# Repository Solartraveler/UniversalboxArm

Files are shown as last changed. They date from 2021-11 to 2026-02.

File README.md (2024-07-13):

# UniversalboxArm

## Idea

Have a box for experiments and easy testing with a CPU which is more powerful than an AVR (Arduino)
and uses less energy than a Raspberry Pi.
Then add some common peripherals and fit this into a case.

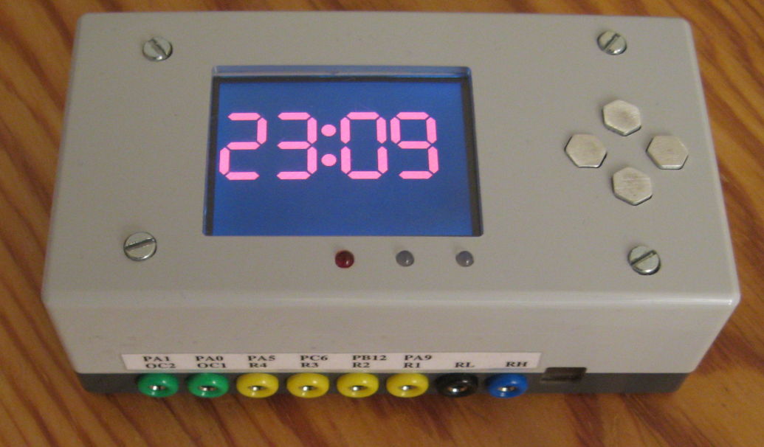
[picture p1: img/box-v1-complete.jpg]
PCB version 1 running, showing a clock


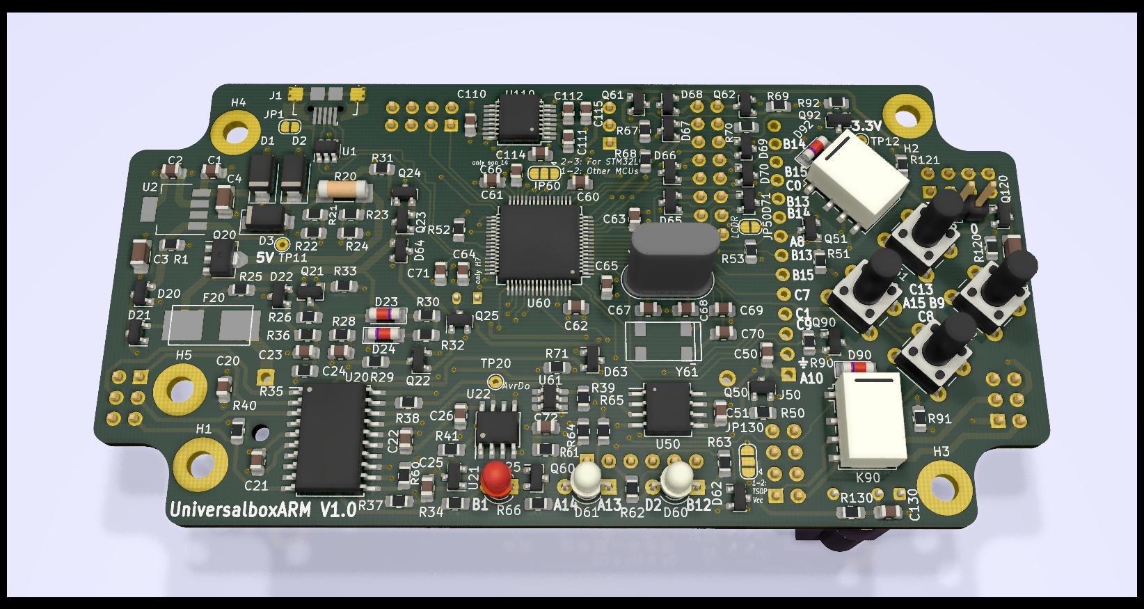
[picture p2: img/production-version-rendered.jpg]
Kicad rendering




## Features

The following hardware has been added. Not everything is required to be populated on the PCB.

- Various 64Pin STM32 MCUs possible

    - STM32L452RET (80MHz, 160KiB RAM) tested

- Runs from USB power

- Can run from a LiFePO battery and charge it

- 2x red-green duo LEDs

- Four buttons

- LCD socket

    - 128x128 (ST7735, tested), 160x128 (ST7735, untested) or 320x240 (ILI9341, tested) RGB LCDs are possible

- Four Relays

- External flash with up to 8MiB

- RS232 level converter

- IR receiver

- WLAN with an ESP-01

- Two open collector outputs

- Several ESD protected in and outputs

- AVR coprocessor for resetting and charge control

## Status

### Software

#### DFU loader for the ARM

A loader for the STM32 MCU is feature complete.

- Can be used by the common dfu-util delivered by the usual Linux distributions (like Debian)

- Accepts applications within a common .tar file together with some metadata

    - With the STM32L452 having 160KiB RAM, the tar file may be up to 128KiB in size.
Needing 2.5KiB overhead for the .tar format and the metadata, the binary may be up to 125.5KiB in size and after starting can use the full 160KiB for code + data.
Executing from RAM results in about 80% of the speed compared with executing from flash with the same CPU frequency.

- The application can be run directly from the RAM or stored into the external flash

    - Transferring to RAM is much faster than writing to the flash. Also there is no worry about the internal flash lifetime.

- Formats the external flash as FAT filesystem

- Allows configuring one of the three LCD sizes

    - Configuration is stored on the external flash and can be read by other applications

- With the four keys and the LCD, applications can be selected from the external flash and run without an USB connection

    - Can set one application as autostarting on power-on

- Each application can have a short descriptive text and explanation image to be shown on the LCD

    - The text can be up to 1KiB long and is taken from the readme.md of each firmware

    - The image is 3 bit RGB and must have the size of the selected LCD or one of the possible smaller LCDs.
Moreover the compressed data needs to fit within 7000byte. Due to RAM constraints, each 4x4 pixel block can not display pixel with more than two different colors.

#### Firmware for the coprocessor

- A long press of the left key resets the ARM processor

- A long press of the right key toggles if a reset should start the DFU bootloader from ST or the application from the flash (most likely the DFU bootloader described above)

- Supports a SPI communication to the ARM processor

    - ARM processor can request a reset

    - ARM processor can enable a watchdog

- The battery can be charged

- A wakeup time for the ARM processor can be set

#### More software

Software testing all the hardware to be working as intended has been written for the ARM processor and the AVR coprocessor.

There is a implementation for using the 8MiB flash as USB pen drive.

One application implements an NTP client and uses the display as digital clock.

See [readme.md](src/apps/readme.md)

### Hardware

The PCB version 1 is working, but a lot of patching is required at several peripherals to use them.
With 380µA, the power down consumption is too high, as this would discharge a full battery within 65 days, and then the LiFePo must be considered defective.
The required changes are documented. Recreating a PCB version 1 is discouraged.
Instead the required changes need to be integrated into a version 2.

Milling the case is done.
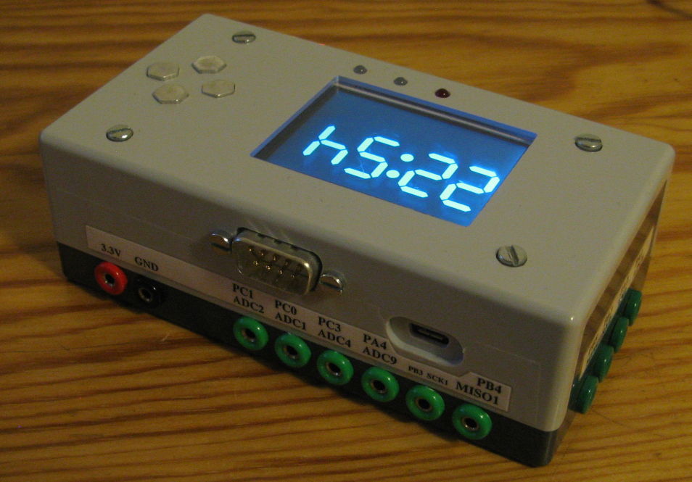
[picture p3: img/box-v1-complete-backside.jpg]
PCB version 1 running, backside


See [readme.md](case/readme.md)

## Using a breadboard

Without soldering an own PCB, some of the apps can be used together with a Nucleo evaluation board from ST.
Then it is just a connection of some wires.
Instead of the onboard flash, the SD card can be used to store settings.
Many of the breakout boards for the LCDs already have a SD card slot on the backside.
The serial port is provided by the nucleo board over USB itself.
One LED and one button is provided by the nucleo board, thee additional buttons can be connected, everthing else is currently missing support.
Currently only the blinky-hal, test-everything and adc-scope apps have been tested on a nucleo with a STM32F411.
As the used board with a STM32F411 only has 128KiB of RAM, it will never be possible to load and execute all apps from RAM there.
However all could made working when running from flash.

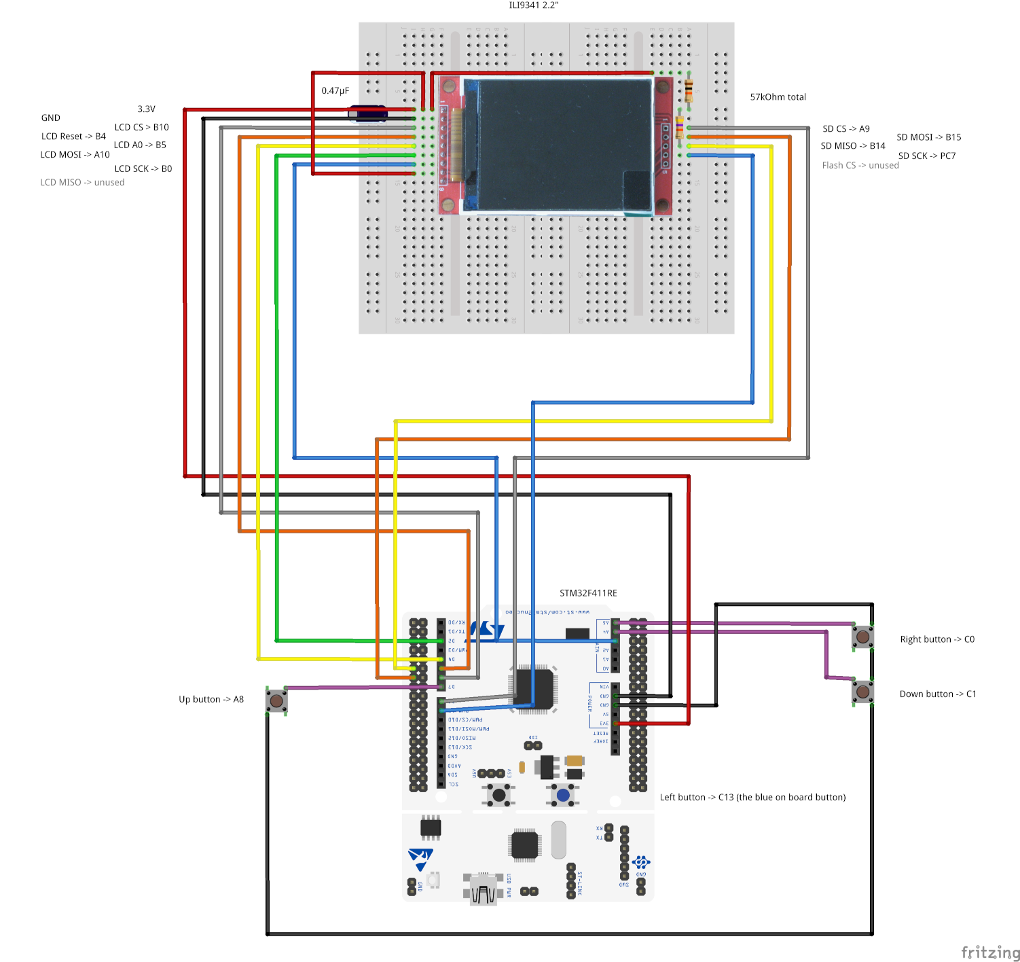
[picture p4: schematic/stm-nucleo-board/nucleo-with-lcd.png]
Wiring of a nucleo to the LCD and SD card


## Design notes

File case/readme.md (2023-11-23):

# Case

The openings are milled with a 2mm flute into a [BOPLA E430](https://www.bopla.de/en/enclosure-technology/element-universal/enclosure-6) case.

Everything is really cramped together in there and still could be placed some 0.1mm to look better. But it works.

Graphic of heights in the case

A E435 with a height of 65mm instead of the 40mm would relax the spacing a lot.

The mill in use has a backslash of 0.1mm, so the files might be modified if the mill is better/worse than this.

The -test files are there to mill a sheet of cheap plastic to test out all the dimensions and to have something to position the mill right on the real case.

The left side could not be milled due to the limit in Z direction. There are no connections on the right and bottom.

# Buttons
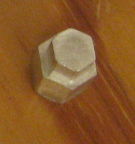
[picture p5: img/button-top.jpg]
Aluminum button top

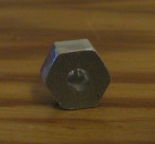
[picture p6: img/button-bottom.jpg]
Aluminum button bottom


The buttons are milled from 10mm aluminum plates (actually a 10.1mm was delivered).
It is difficult to get them right, as 0.2mm wrong in the one or other direction let them wiggle or let them sit so tight they are pressed permanently.

Also when buying 10mm alumium plates, they might be up to +-0.5mm in thickness and the files for milling need some adjustents according to the exact value.

Note, by screwing the case together, the surface also bends a little bit inward, which has to be taken care of too.

## File formats

.FCStd -> .step -> .heeks -> .ngc

## FreeCAD
All models were first created with [FreeCAD](https://www.freecad.org/) 0.21. If in doubt, try only this version to open the files.

FreeCAD saves its files as .FCstd. The 3D model is exported from FreeCAD as .step file.

## HeeksCAD
[HeeksCAD](https://github.com/Heeks/heekscad) together with [HeeksCNC](https://github.com/Heeks/heekscnc) Is used to create the paths for the CNC mill.

HeeksCAD imports .step files, saves them to .heeks and creates .ngc files.

Don't try to get HeeksCNC to work on a modern (Debian 12 as of writing this) system (HeeksCAD does work), it needs Python 2 with boost compiled against Python 2.
So instead set up a VM with Debian 10. HeeksCNC works fine with X-forwarding.

FreeCAD could be used to create the milling paths too, but the ones from HeeksCNC are better (as of 2023).

## Candle2

[Candle2](https://github.com/Schildkroet/Candle2) now reads the .ngc files and drives a modified Proxxon MF70 mill with [grbl](https://github.com/grbl/grbl).

## xfig

The .fig files can be opened by [xfig](https://mcj.sourceforge.net/). From there the .svg or .pdf files are exported.

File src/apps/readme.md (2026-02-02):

# Firmwares for the STM32L452 processor

## Common

Library code used by multiple projects.

## 01-blinky-hal

Project showing that running the ARM works. The LEDs D61 and D62 are blinking and
are responding to the four input keys. This project uses the HAL library from ST.

## 02-test-everything-hal

Uses a RS232 port with 19200baud to allow controlling all connected hardware.

## 03-loader

__Main firmware__ intended to be progammed into the internal flash.
Provides a DFU device via USB to upload new programs.
Also writes a configuration in the external flash for the selected LCD type.
Can store and load programs from the external flash. Formatting can be done too.
Debug prints are available over the RS232 port with 19200baud.

## 04-coprocessor-uart-forward

If the coprocessor is running the 02-test-everything firmware, it prints data at 1200baud on the pins connected to the ARM.
With this firmware the data is forwared to the RS232 port with 19200baud and prints the data on the LCD too.

## 05-coprocessor-control

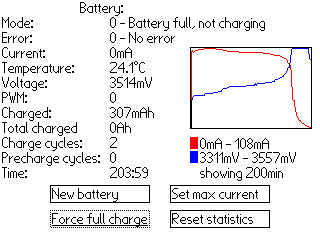
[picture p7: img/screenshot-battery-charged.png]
Screenshot after charging the battery


If the coprocessor is running the 05-charger-with-spi firmware, this firmware allows reading out the charger state, resetting
the charger state and playing with the power off features.
Debug prints are available over the RS232 port with 19200baud.

## 06-usb-mass-storage

Connect the external SPI flash as USB mass storage device to the PC, allows reading and writing files on the disk.
As always, Debug prints are available over the RS232 port with 19200baud.

## 07-ntp-clock

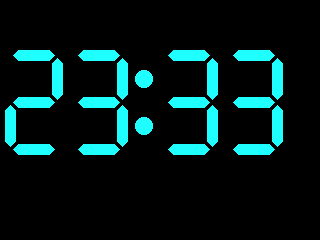
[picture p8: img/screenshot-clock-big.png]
Screenshot of the big clock


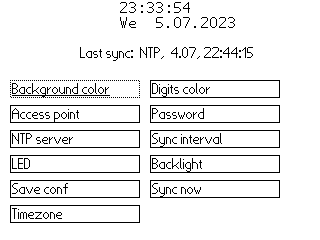
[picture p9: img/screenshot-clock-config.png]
Screenshot of the configuration


Shows a big digital clock on the screen. Foreground and background color can be configured out of 256 colors.
The clock is synced over WIFI with an NTP server, therefore AP, password and NTP server can be set.
The backlight level and timezone can be set and the internal clock is calibrated automatically
when there are two syncs with enough time inbetween.
If a battery is connected, the clock continues to run while the device is off.
To allow updateing the GUI while the WIFI is served, FreeRTOS is used.
All settings are saved to the filesystem.
Debug prints are available over the RS232 port with 19200baud.
Also entering the AP and password is much easier over the RS232 port.

## 08-freertos-helloworld
Simple example how to use FreeRTOS.
Starts four threads, one for reading the serial port, one for resetting the watchdog, one for flashing the LEDs and one for reading the buttons.

## 09-gamebox

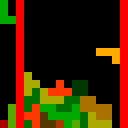
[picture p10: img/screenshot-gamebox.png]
Screenshot of the gamebox, playing tetris


Port of an old project, originally written for an AVR with a red/green LED matrix.
Play Tetris, Snake, Four winns, Reversi, Race or Pong with just 16x16 pixels and 4 bit colors.
Also contains a demo.
Best used with an analogue joystick. But the input keys work too.
Tetris, Snake, Four winns, Reversi can also be played over the RS232 input, using w-a-s-d as cursor and space for enter.
The sourcecode is pretty old and still commented in german.
Running the gamebox on the AVR can be watched on [Youtube](https://www.youtube.com/watch?v=83r08iD9ZAA)
The connection of the analogue joystick to the STM32 is as follow:
Schematic for d-sub connection

## 10-infrared-decoder

Prints the protocol, address, command and flags of many infrared remote controls on the LCD and
serial port.

## 11-adc-scope

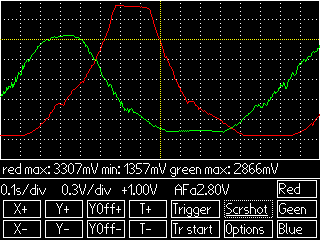
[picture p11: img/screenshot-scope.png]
Screenshot of the scope


Shows the analogue inputs on the display. Only supports 320x240 LCD.

Features:

- 200kHz sample rate (limit is the CPU checking the trigger condition, the ADC could be 20x faster)

- Select 3 Inputs out of all available ADC inputs

- Selectable X (time) and Y (voltage) scaling

- Selectable Y offset

- Trigger: Level, rising or falling edge. Normal or single shot.

- Max, min and average voltage analysis per channel

- Save screenshors and save/restore selected settings

Note: This is __not__ a fully featured oscilloscope.
It is intended to easy see what the AD values on the inputs are.
For example you can analyze the input signals if a joystick for 09-gamebox is connected and does not work as expected.
Actually the screenshot shows the signal while moving the two axis of the joystick.

Features __missing__ to be a real oscilloscope replacement:

- Selctable X offset - the trigger is always in the middle of the screen

- Y scaling and offset separated per channel

- X-Y mode

- Reasonable samplerate for signals above ~20kHz

- Defined input impendance

- Selectable input gain

- Support of negative input voltages

- Proper capture of every trigger event and displaying this as greyscale value

- Reasonable calibration. The internal oscillator might have +-2% error on the X axis

- Rotary encoders for a fast-to-use user interface. Four buttons are really limited.

- Proper analogue/digital separation on PCB

## 12-usb-cdc-loop

Ported USB cdc loop sample from [Libusb_stm32](https://github.com/dmitrystu/libusb_stm32).

After starting, an USB to serial converter is registered. All data transmitted are looped
back to the input. This allows testing the USB connection.

## 13-battery-capacity-tester

Discharges a battery with the help of an external resistor until a minimum voltage is reached.
Then the discharged capacity is written to a log file.
While the software supports to discharge and measure two batteries at the same time, this requires
the relays to be connected in a way the positive outputs of the batteries can not be connected together.
Otherwise limit the use to one battery.
Input voltage limit is ~14V and the maximum discharge current by the selected load resistor must be limited to 2A.

## 14-wav-player

Plays a normal uncompressed audio .wav file over one 8 bit PWM channel from the internal flash.
[Needs some external components](https://www.mikrocontroller.net/articles/Klangerzeugung#Lautsprecher) to be connected to port B, pin 4.
Supports:
- 8 and 16bit PCM
- mono and stereo
- 100Hz to 44200Hz samplerate

16bit and stereo files are automatically converted to 8 bit mono.
Other formats are not supported.
The .wav file can be transferred to the flash with the 06-usb-mass-storage project.

The audio quality can not be compared to a normal computer, it is more on the level of a telephone or a cheap toy doing some sounds.
The reason is the simple A/D conversion with a 128kHz PWM signal.

## 15-mp3-player

Plays a normal audio .mp3 file over one 8 bit PWM channel from the internal flash. Very similar to 14-wav-player.
[Needs some external components](https://www.mikrocontroller.net/articles/Klangerzeugung#Lautsprecher) to be connected to port B, pin 4.
Tested for files up to 128KBit/s.
At the end of the file performance statistics are printed.
This is useful to estimate the needed computing power for an mp3 player project using libmad.

The .mp3 file can be transferred to the flash with the 06-usb-mass-storage project.

The audio quality can not be compared to a normal computer, it is more on the level of a telephone or a cheap toy doing some sounds.
The reason is the simple A/D conversion with a 312,5kHz PWM signal.
Stereo is converted to mono.

## 16-led-matrix-tester

Connect up to thee LEDs to external pins (might be one RGB LED) and control their brighness.
LED 1 of the box can be controlled too.
The intention is to test the actual brightness for using the LEDs in a matrix configuration.
The number of colors, number of lines in a matrix and refresh rate can be configured.
Then the duty cycle can be set for every LED.
So this program basically provides 5 software generated PWM channels.

## 17-sdcard-playground

Determines properies of SD cards not to be found with an USB card reader and
usually not found in any datasheet.

Can be used to scan SD cards for bad blocks, determine read acces times and undocumented reset behaviour.

## 18-dac-tester

Tests the DAC (digital analog converter).
Pretty simple.
Select a 1Hz sawtooth, 1kHz sine or a 1MHz rectangle signal to be outputted to the DAC channel with a DMA transfer.
The 1MHz is out of the limit of the DAC and will result in a triangle.

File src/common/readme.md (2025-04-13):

# Shared files for STM, AVR processor and probably anything else

# algorithm
Useful platform independend algorithm by the author of this project.

License: BSD 3-Clause

# fatfs #
Fat filesystem from (http://elm-chan.org/fsw/ff/00index_e.html) version 0.14b.

License: BSD 1-Clause

# FreeRTOS
FreeRTOS from (https://github.com/FreeRTOS/FreeRTOS-Kernel) version 10.5.1

License: MIT

## ili9341 ##
Files for the 320x240 GLCD.

License: BSD 3-Clause

The header and the unused ili9341_st_not_working.c file are taken from [STM32Cube_FW_F4_V1.25.2](https://github.com/STMicroelectronics/STM32CubeF4/releases/tag/v1.25.2)

The actual working init sequence in ili9341.c is taken from
[here](https://vivonomicon.com/2018/06/17/drawing-to-a-small-tft-display-the-ili9341-and-stm32/)

# irmp
IRMP, the [infrared multiprotocol decoder library](https://www.mikrocontroller.net/articles/IRMP).
The files are taken from the .zip archive version 3.2.6 (27.01.2021).

License: GPL v2 or newer

# jsmn
Json parser from (https://github.com/zserge/jsmn) version 1.1.0

License: MIT

# lwip
Just for md5sum calculation.

Files taken from [LwIP](https://savannah.nongnu.org/projects/lwip/) version 2.1.3.

License: BSD 3-Clause

# menuInterpreter
GUI toolkit from the author of this project. Version 2.1.
The full project can be found at [Sourceforge](https://sourceforge.net/projects/menudesigner/)

License: MPL-2.0

## st7735 ##
Files for the 128x128 GLCD

License: BSD 3-Clause

Taken from [STM32Cube_FW_L4_V1.16.0](https://github.com/STMicroelectronics/STM32CubeL4/releases/tag/v1.16.0)

## libmad ##
Libmad - MPEG audio decoder library

License: GPL v2 or newer

Taken from GIT [version 0.16.4 commit ee7c3cdd4361b7f7c7da52fa3ba9f76cc35230a9](https://codeberg.org/tenacityteam/libmad/releases/tag/0.16.4)

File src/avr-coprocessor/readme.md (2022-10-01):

# Firmware for the AVR coprocessor #
All projects contain a pc-simulator folder which allows simulating the firmware on a PC.
The key inputs are than the left and right cursor keys and a circle shows the state of the the red LED.

## 01-minimal-reset-button ##
Project to use when nothing but reset and bootmode should be controlled.
No further communication with the ARM is done (no need for U22 and U61).
No battery charging or supply by battery is supported. Runs at 128kHz internal clock.

## 02-test-everything ##
Connect a TTL level serial port at 1200baud (no stopbit) to PA1 (TP20) and get a debug output.
Or set the serial output in hardware.h to use PB1 instead, then the MISO pin on J20 can be used.
The mode to test can be selected with the left key, and executed with the right key.
When using this, no battery should be connected, as no current limiting is done and
the voltage is not watched. The fuse bits need to be set to use the 8MHz internal clock
and the MCU runs with 1MHz internally.

Instead of connecting a TTL level converter, the ARM CPU can run the 04-coprocessor-uart-forward firmware.
The the ARM is forwarding the data from to his own RS232 port and shows a printout on the LCD.
This works if the debug output is routed to PA1.

## 03-reset-button-with-spi ##
Provides the same functionality as 01-minimal-reset-button, but the MCU acts as SPI slave to the ARM master.
The reset mode can be controlled over this interface, and the input voltage can be read out.
Suitable firmware if no battery functionality is added.

## 04-charger-unittests ##
Unit tests for the charger logic.
Can be run on the PC or (partially, because the flash is full) on the AVR.
It's pure calculation.
No input is evaluated.
The AVR results are printet with 1200baud to PA1, like 02-test-everything.

## 05-spi-with-charger ##
This is the main firmware to use.
Provides the same functionality as 03-reset-button-with-spi but with all the extras for charging the battery.
For this a lot of extra SPI commands are available.

## 06-chip-bug-didr0-test ##
Some tests for tracking down issues found while implementing 05-spi-with-charger. So far this test does not find any bugs.

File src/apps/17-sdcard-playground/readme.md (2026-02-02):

Test characteristics of SD cards, not found in a datasheet.

SD     Controller

Vcc -> +3.3V

CS  -> PA1

DI  -> PB5

DO  -> PB4

SCK -> PB3

GND -> PA0 (via mosfet)

Example:

Read every sector until a non working one is found (speed is about 600KB/s):

command: 17 (0x11 - read single block)

argument: 0

powercycle: false

increment: 1 for SDHC/SDXC, 512 (0x200) for SD/MMC

checkread: false

stop on found: true

seek for: failure

require data: false

max transfer length: 51200

min divider: 4 (some cards might need a higher one as the transfer length can't be increased)

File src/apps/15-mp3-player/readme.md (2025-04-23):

Plays a .mp3 file

Select a mp3 audio file. Then it can be played with some extra external components.

PWM generation is limited to 8bits, so do not expect high quality sound.

Tested for mp3 files with up to 128kBit/s datarate.

sox -n -r 24000  "$(BUILD_DIR)/sine-600Hz-1ch-24k.mp3" synth 5 sine 600

Schematic for playback: https://www.mikrocontroller.net/articles/Klangerzeugung#Lautsprecher

The LED 1 lights red if the output FIFO underruns.

Performance data are printed to the serial port at the end of a file, not if manually stopped.

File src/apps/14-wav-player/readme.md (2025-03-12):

Plays a .wav file

Select a wave audio file. Then it can be played with some extra external components.

PWM generation is limited to 8bits, so do not expect high quality sound.

However all uncompressed 8Bit and 16Bit mono and stereo .wav files should work.

Convert files to 8 bit single channel and 8kHz samplerate with:

ffmpeg -i input.wav -ac 1 -acodec pcm_u8 -ar 8000 output8k.wav

Schematic for playback: https://www.mikrocontroller.net/articles/Klangerzeugung#Lautsprecher

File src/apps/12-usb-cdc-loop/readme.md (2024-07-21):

CDC loop sample

Provides a USB device with a serial port.

All data are mirrored back to the source. So it can be used for testing USB.

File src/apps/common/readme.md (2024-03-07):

# Shared files for the ARM processor #

## boxlib ##
Files from the author of this project

License: BSD 3-Clause

## CMSIS ##
CMSIS header files from ARM and ST

License: Apache 2.0

Taken from STM32Cube_FW_L4_V1.16.0

and

STM32Cube_FW_F4_V1.25.2

## libusb_stm32 ##
Usb communication library

License: Apache 2.0

Files taken from
[Libusb_stm32](https://github.com/dmitrystu/libusb_stm32) commit #fd58c2b

# pc-simulator #
From the author of this project. Includes everything to run a program on a developer system without an ARM too.
Useful for developing and debugging.

License: BSD 3-Clause

## shared-init
Files from ST. Linker scripts and init assembly routines.

License: Apache 2.0 and BSD 3-Clause

## stm32l4xx_HAL_Driver ##
Files from ST.

License: BSD 3-Clause

Taken from STM32Cube_FW_L4_V1.16.0

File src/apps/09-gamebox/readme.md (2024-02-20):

Gamebox

Play Tetris, Snake, Four winns, Reversi, Race or Pong.

Also contains a Demo.

Connect an analogue joystick to have more fun playing the games!

When using the cursor keys, pressing up and down at the same time is the same as
the fire button.

MCU reset with the left key is prolonged to 8s, instesad of the normal 1s.

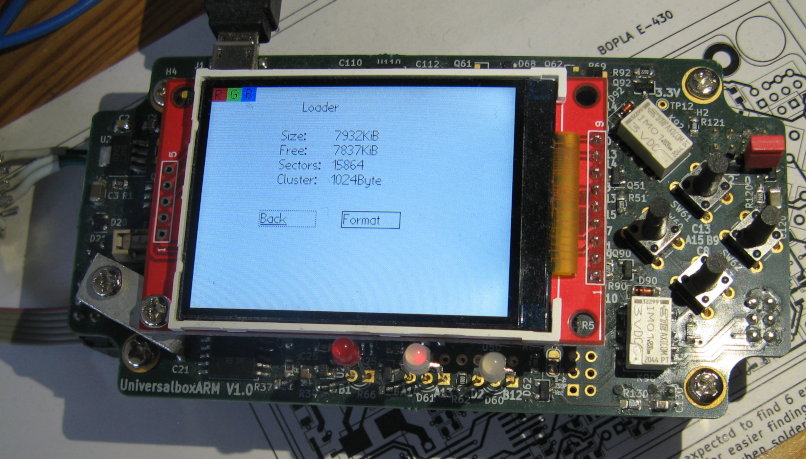
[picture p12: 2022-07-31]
img/pcb-v1-running-dfu-loader.jpg

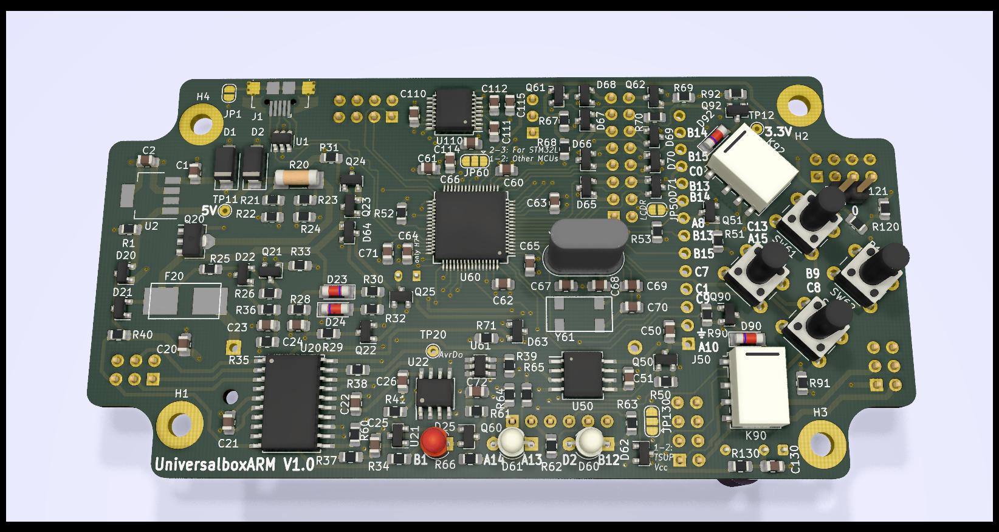
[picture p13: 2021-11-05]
img/early-version-rendered.jpg

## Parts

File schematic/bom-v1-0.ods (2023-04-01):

Universalbox ARM, PCB version 1, schematic revision 0.8
Part | Number | Description | Reichelt ordernumber | RS ordernumber | Price/Part | Price total
 | 1 | Battery LIFEPO4 | XC IFR 14500 |  | 4,50 € | 4,50 €
BT20 | 1 | Battery holder | KEYSTONE 1015 |  | 1,99 € | 1,99 €
C1, C2, C20, C23 | 4 | 10µF 16V 0805 | X5R-G0805 10/16 |  | 0,05 € | 0,20 €
C21, C22, C26, C50, C51, C60, C61, C62, C63, C64, C65, C72, C110, C111, C112, C114, C115 | 17 | 100nF 0805 | X7R-G0805 100N |  | 0,04 € | 0,68 €
C24 | 1 | 10nF | X7R-G0805 10N |  | 0,04 € | 0,04 €
C25 | 1 | 470nF | KEM X7R0805 470N |  | 0,07 € | 0,07 €
C120, C130 | 1 | 4.7µF | KEM X5R0805 4,7U |  | 0,10 € | 0,10 €
C66 | 0 | 4.7µF only for STM32F4, F7 or H7 | KEM X5R0805 4,7U |  | 0,10 € | 0,00 €
C71 | 0 | 4.7µF only for STM32H7 | KEM X5R0805 4,7U |  | 0,10 € | 0,00 €
C69, C70 | 2 | 22pF for 8MHz crystal | KEM C0G0805 22P |  | 0,04 € | 0,08 €
C67, C68 | 2 | 10pF for 32768Hz crystal | NPO-G0805 10P |  | 0,02 € | 0,04 €
C3, C121 | 2 | 100µF 1206 | X5R-G1206 100/6 |  | 0,27 € | 0,54 €
C4 | 0 | 100µF 1206 | X5R-G1206 100/6 |  | 0,27 € | 0,00 €
D1, D2, D3 | 3 | SK14, Schottky 40V, 1A | SK 14 DIO |  | 0,04 € | 0,12 €
D20, D21, D62, D63, D64 | 5 | BAT54C, Dual schottky, 30V, 0.2A, common cathode | BAT 54C NXP |  | 0,04 € | 0,20 €
D22 | 1 | TL431BIDBZT, 2.45V 0.5% regulator |  | 661-9534 | 1,02 € | 1,02 €
D23, D90, D91, D92, D93 | 5 | BAS32, Schottky 100V 0.2A | BAS 32 SMD |  | 0,05 € | 0,25 € | min order 5
D25 | 1 | LED 3mm orange or red | EVL 264-7SURD |  | 0,08 € | 0,08 €
D60, D61 | 2 | LED 3mm red + green | EVL 209SURSYGW |  | 0,22 € | 0,44 €
D65, D66, D67, D69, D70, D71 | 6 | PESD5V2S2UT, Dual 5,2V ESD protection | PESD5V2S2UT |  | 0,17 € | 1,02 €
D68 | 9 | PESD24VS2UT, Dual 24V ESD protection |  | 170-5359 | 0,38 € | 3,38 € | min order 50
R31, R53 | 2 | TS4148 RY, originally resistors in first PCB version | TS 4148-0805 |  | 0,03 € | 0,06 €
F20 | 1 | Fuseholder with 0,5A fuse | LITT 0154.500DR |  | 2,30 € | 2,30 €
J1 | 1 | Micro USB jack | MIC USB BBU |  | 0,50 € | 0,50 €
J20 | 1 | AVR ISP, 2x3 male pin 2.54mm | SL 2X25G 2,54 |  | 0,32 € | 0,64 €
J61 | 1 | External pins, 2x8 male pin 2.54mm
J90 | 1 | Relais common pins, 2x3 male pin 2.54mm
J91 | 1 | Relais separate pins, 2x4 male pin 2.54mm
J62 | 1 | H-bridge and power supply pins, 2x8 male pin 2.54mm
J60 | 1 | STLINK 1x6 male pin 2.54mm | SL 1X36G 2,54 |  | 0,18 € | 0,18 €
J110 | 1 | RS232 pins, 1x3 male pin 2.54mm
J121 | 0 | ESP-01 GPIO connection, firmware update mode 1x2 male pin 2.54mm
J50 | 1 | LCD socket 2.54mm 14pol, max 7mm height to fit in case Selected one has 5,7mm height | BKL 10120952 |  | 0,92 € | 0,92 €
J120 | 1 | ESP-01, 2x4 female pin 2.54mm | MPE 094-2-008 |  | 0,31 € | 0,31 €
K90, K91, K92, K93 | 4 | Relai 3.3V, 2A | IM01GR | 909-7930 | 2,42 € | 9,68 €
Q20 | 1 | BCX 56-16, NPN, 80V, 1A, 1W | BCX 56-16 NXP |  | 0,15 € | 0,15 €
Q21, Q22, Q25, Q60, Q90, Q91, Q92, Q93 | 8 | BSS138, Mosfet, N, 0.36A, 60V | BSS 138P NXP |  | 0,06 € | 0,48 €
Q61, Q62 | 2 | IRLML 6344, Mosfet, N, 5A, 30V | IRLML 6344 |  | 0,52 € | 1,04 €
Q23, Q24, Q50, Q51, Q120 | 5 | IRLML 6402, Mosfet, P, 3.7A, 20V | IRLML 6402 |  | 0,25 € | 1,25 €
R20 | 1 | 3,9Ohm, 1W, MELF207 | VIT ZC207 3,9R |  | 0,16 € | 0,16 €
R36 | 1 | 100Ohm, 0805 | SMD-0805 100 |  | 0,03 € | 0,03 €
R37 | 1 | 150Ohm, 0805 | SMD-0805 150 |  | 0,03 € | 0,03 €
R52, R62, R64, R66, R71, R121, R130 | 7 | 180Ohm, 0805 | SMD-0805 180 |  | 0,03 € | 0,21 €
R68, R70 | 0 | 180Ohm, 0805 | SMD-0805 180 |  | 0,03 € | 0,00 €
R35, R63, R65, R72 | 4 | 330Ohm, 0805 | SMD-0805 330 |  | 0,03 € | 0,12 €
R34 | 1 | 470Ohm, 0805 | SMD-0805 470 |  | 0,03 € | 0,03 €
R41 | 1 | 1k, 0805 | SMD-0805 1,00K |  | 0,03 € | 0,03 €
R33 | 1 | 4,7k, 0805 | SMD-0805 4,70K |  | 0,03 € | 0,03 €
R25 | 1 | 9.1k, 0805, 0.1% | SPR-0805 9,10K |  | 0,25 € | 0,25 €
R32 | 1 | 10k, 0805 | SMD-0805 10,0K |  | 0,03 € | 0,03 €
R38 | 1 | 12k, 0805 | SMD-0805 12,0K |  | 0,03 € | 0,03 €
R22, R24 | 2 | 15k, 0805 | SMD-0805 15,0K |  | 0,03 € | 0,06 €
R26 | 1 | 22k, 0805, 0.1% | SPR-0805 22,0K |  | 0,25 € | 0,25 €
R39 | 1 | 22K, 0805 | SMD-0805 22,0K |  | 0,03 € | 0,03 €
R21, R23 | 2 | 33k, 0805 | SMD-0805 33,0K |  | 0,03 € | 0,06 €
R28, R29 | 2 | 47k, 0805 | SMD-0805 47,0K |  | 0,03 € | 0,06 €
R50, R120 | 2 | 56k, 0805 | SMD-0805 56,0K |  | 0,03 € | 0,06 €
R1, R40 | 2 | 100k, 0805 | SMD-0805 100K |  | 0,03 € | 0,06 €
R30, R51, R60, R61, R90, R91, R92, R93 | 8 | 220k, 0805 | SMD-0805 220K |  | 0,03 € | 0,24 €
R67, R69 | 2 | 220k, 0805 | SMD-0805 220K |  | 0,03 € | 0,06 €
SW60, SW61, SW62, SW63 | 4 | taster 6mm*6mm 13mm height | JTP-1130 |  | 0,16 € | 0,64 €
TH20 | 1 | KTY 81-221, temperature sensor 2K | KTY 81-221 |  | 0,56 € | 0,56 €
U1 | 1 | USBLC6-2SC6, USB ESD protection | USBLC6-2SC6 |  | 0,18 € | 0,18 €
U2 | 1 | LP 38693MP-3.3, 3.3V ldo regulator, 0.5A | LP 38693 MP-3.3 |  | 1,75 € | 1,75 €
U20 | 1 | AVR | ATTINY 861A-SU |  | 1,25 € | 1,25 €
U21 | 1 | 2V reference | REF 3020 AIDBZT |  | 1,35 € | 1,35 €
U22 | 1 | MCP6542, 2x comparator | MCP 6542-I/SN |  | 0,55 € | 0,55 €
U50 | 1 | AT45DB641-S, 64MBit SPI flash | AT45DB641E-SHN |  | 3,58 € | 3,58 €
U60 | 1 | STM32L452RET, 80MHz, 160KiB RAM |  | 189-4029 | 8,22 € | 8,22 € | min order 2
 | 0 | STM32L496RET alternate with 320KiB RAM | STM32L496RET6 |  | 13,00 € | 0,00 €
U61 | 1 | 1x low power comparator with 1.2V reference | MCP 65R41T-1202E |  | 0,55 € | 0,55 €
U110 | 1 | MAX3221 | MAX 3221 ECAE |  | 2,95 € | 2,95 €
U130 | 1 | TSOP31236, IR receiver 36KHz | TSOP 31236 |  | 0,56 € | 0,56 €
Y60 | 0 | 32768Hz crystal, Cl: 12,5pF, case wrong | 0,032768-SMD |  | 0,40 € | 0,00 €
 | 1 | 32768Hz crystal, Cl: 10pF, fix for wrong case | 0,032768 |  | 0,20 € | 0,20 €
Y61 | 1 | 8MHz crystal | 8,0000-HC49U-S |  | 0,25 € | 0,25 €
 | 1 | BOPLA-E430 case | BOPLA E-430 |  | 11,95 € | 11,95 €
 | 1 | RS232 connector | D-SUB ST 09 |  | 0,15 € | 0,15 €
 |  |  | ---------------------------------------------------------
 | 0 | LCD 160x128 |  |  | 8,95 € | 0,00 €
 | 1 | LCD 128x128 |  |  | 7,50 € | 7,50 €
 | 0 | LCD 320x240
 | 1 | ESP-01 |  |  | 5,29 € | 5,29 €
 | 1 | PCB service | AISLER 4-layer |  | 19,60 € | 19,60 € | min order 3
 |  |  |  |  | Total | 101,16 €

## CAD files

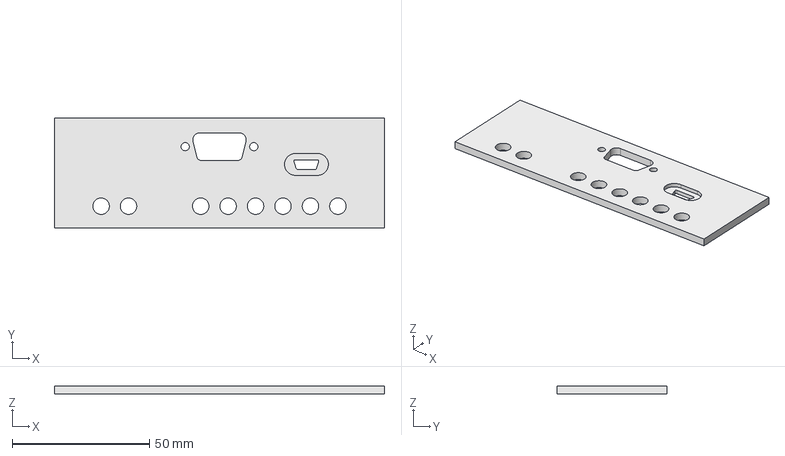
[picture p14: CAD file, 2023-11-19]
case/forPcbVersion1/backside/backside-fc21-5.step
120.3 x 40.2 x 3.00 mm

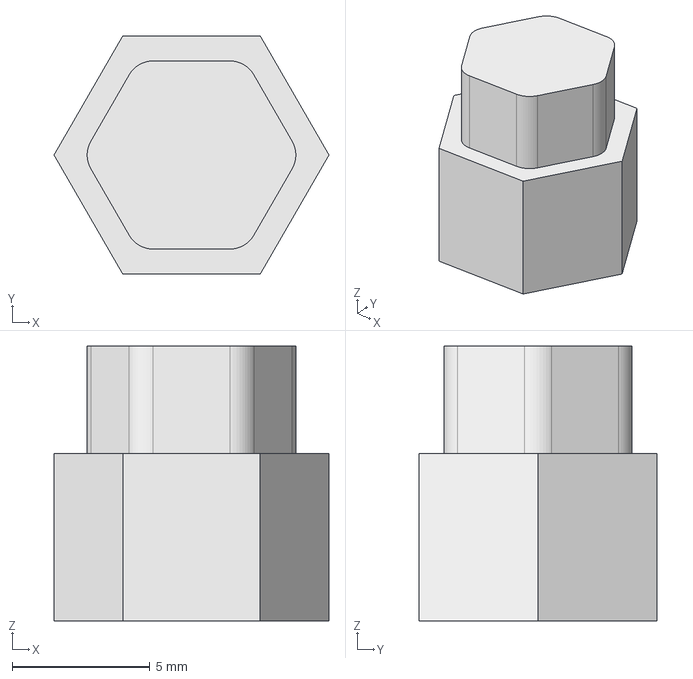
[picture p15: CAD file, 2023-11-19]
case/forPcbVersion1/button/button-fc21-6.step
10.0 x 8.66 x 10.0 mm

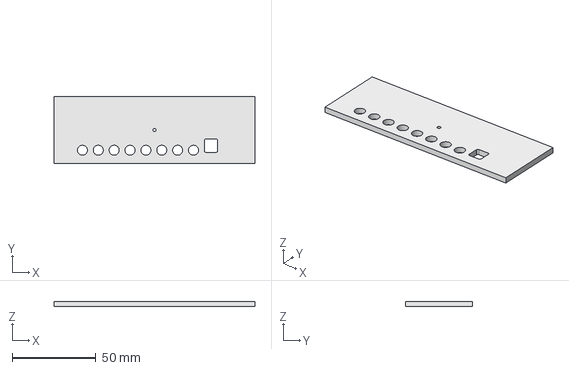
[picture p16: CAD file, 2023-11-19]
case/forPcbVersion1/frontside/frontside-fc21-2.step
120.3 x 40.2 x 3.20 mm

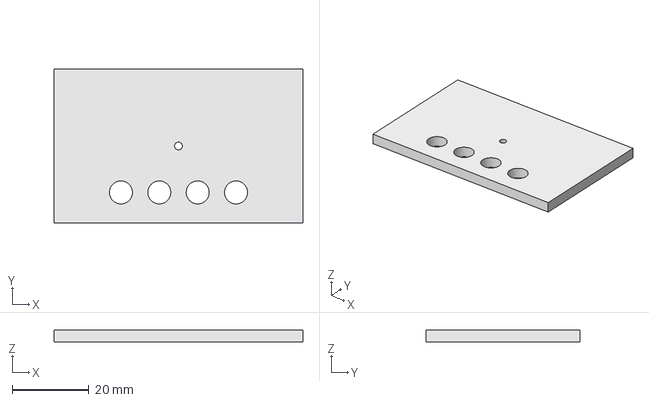
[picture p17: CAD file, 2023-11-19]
case/forPcbVersion1/leftside/leftside-fc21-1.step
64.9 x 40.2 x 3.20 mm

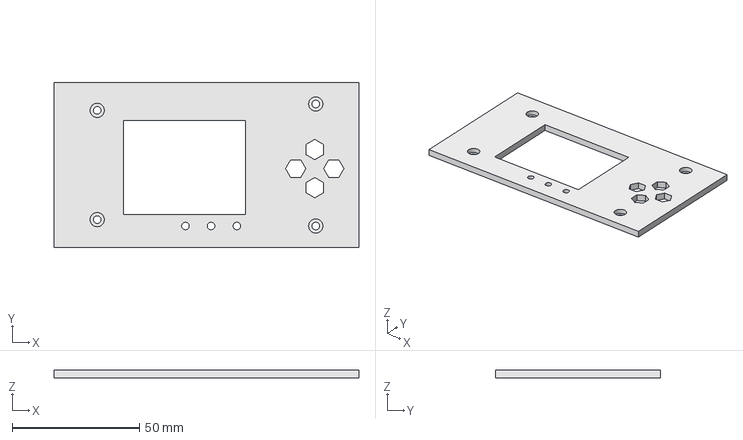
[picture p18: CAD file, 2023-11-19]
case/forPcbVersion1/top/top-fc21-3.step
120.0 x 65.0 x 3.00 mm

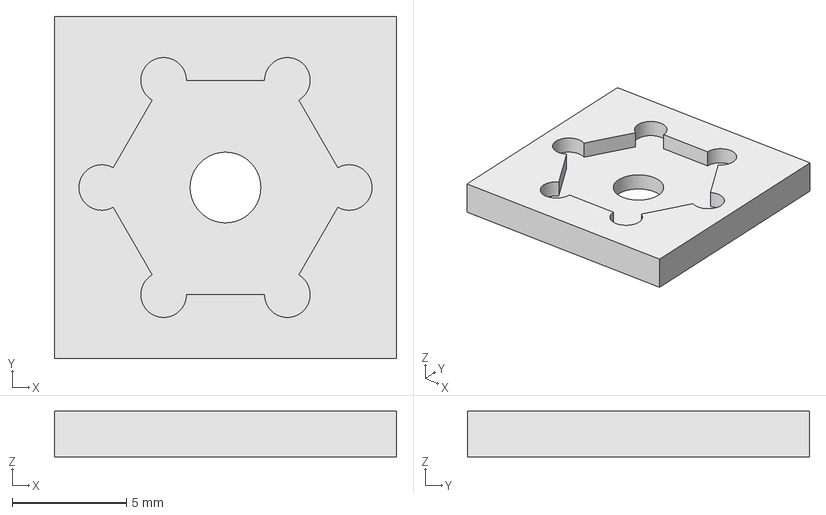
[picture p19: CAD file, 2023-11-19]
case/forPcbVersion1/button/drillingHolder-fc21-2-Body.step
15.0 x 15.0 x 2.00 mm

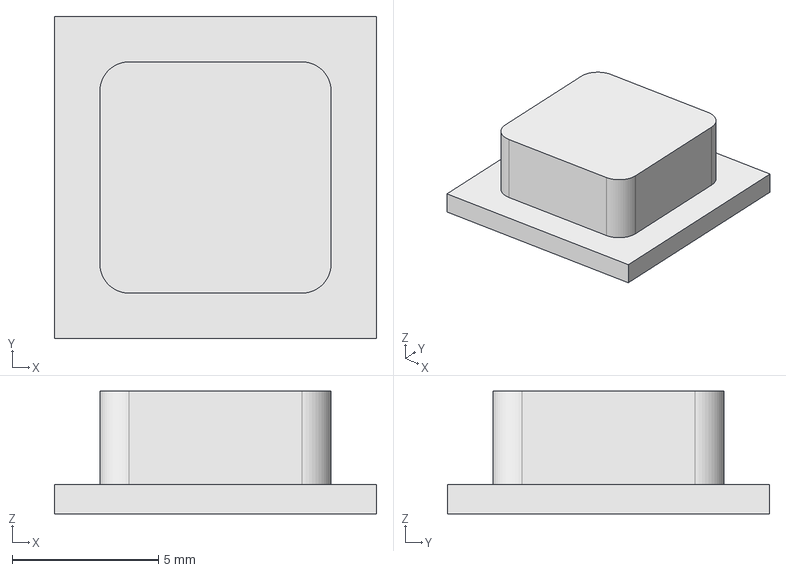
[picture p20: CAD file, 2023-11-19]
case/forPcbVersion1/frontside/ir-window-fc21-1.step
11.0 x 11.0 x 4.20 mm

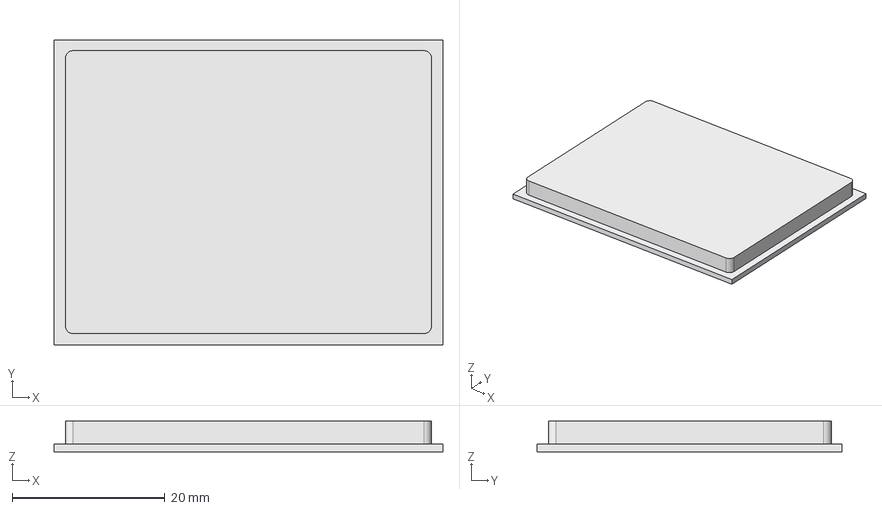
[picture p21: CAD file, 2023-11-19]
case/forPcbVersion1/top/lcdwindow-fc21-1.FCStd
51.0 x 40.0 x 4.00 mm

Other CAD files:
case/forPcbVersion1/button/drillingHolder-fc21-2.FCStd
case/forPcbVersion1/top/lcdwindow-fc21-1-Body.step
case/forPcbVersion1/backside/backside-fc21-5.FCStd
case/forPcbVersion1/button/button-fc21-6.FCStd
case/forPcbVersion1/frontside/frontside-fc21-2.FCStd
case/forPcbVersion1/frontside/ir-window-fc21-1.FCStd
case/forPcbVersion1/leftside/leftside-fc21-1.FCStd
case/forPcbVersion1/top/top-fc21-3.FCStd

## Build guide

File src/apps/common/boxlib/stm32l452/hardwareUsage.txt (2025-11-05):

Shared sources:

adcDac:         DMA1 Channel 1
clock:          RTC
esp:            USART3, USART3_IRQHandler
keysIsr:        EXTI9_5_IRQHandler, EXTI15_10_IRQHandler
lcdBacklight:   TIM1
peripheral:     SPI2
peripheralDma:  SPI2, DMA1 Channel 4, DMA1 Channel 5
rs232debug:     USART1, USART1_IRQHandler
sequenceToPwm:  TIM3, TIM16, TIM1_UP_TIM16_IRQHandler
spiExternal:    SPI1
spiExternalDma: SPI1, DMA1 Channel 3, DMA1 Channel 2
stackSampler:   TIM15, TIM1_BRK_TIM15_IRQHandler
timer32Bit:     TIM2
timer16Bit:     TIM6

Apps:
09-gamebox:     TIM15
11-adc-scope:   TIM2, TIM2_IRQHandler
18-dac-test:    TIM6, DMA1 Channel 3

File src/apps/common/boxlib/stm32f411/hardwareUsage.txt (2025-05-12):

Shared sources:

keysIsr:       EXTI0_IRQHandler, EXTI1_IRQHandler, EXTI9_5_IRQHandler, EXTI15_10_IRQHandler
spiExternal:   SPI2
peripheral:    SPI5
timer32Bit:    TIM2
timer16Bit:    TIM10
rs232debug:    USART2, USART2_IRQHandler

Apps:
11-adc-scope:  TIM2, TIM2_IRQHandler

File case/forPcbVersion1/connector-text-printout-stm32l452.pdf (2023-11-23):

PA1
OC2 | OC1
PA0 | PA5 | PA9
R1 | RL | RHR3 | R2

PB12PC6
R4

PA1
OC2 | OC1
PA0 | PA5 | PA9
R1 | RL | RHR3 | R2

PB12PC6
R4

PA1
OC2 | OC1
PA0 | PA5 | PA9
R1 | RL | RHR3 | R2

PB12PC6
R4

# Backside, raster 10mm

# Left side, raster 10mm

# Front side, raster 9.5mm

3.3V

PC0 | PC3PC1
ADC2 | ADC1 | ADC4 | ADC9 PA4
MISO1GND

PB5
MOSI1RX2
PA3 | PA2
TX2 | ADC6

PA1

PB4

SCK1PB3

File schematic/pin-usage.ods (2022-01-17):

STM32L452RET6 / STM32L452RCT6 Other devices are not checked!
 | External = with ESD protection, Internal = no extra ESD protection
Internal GPIO: at some pin header a wire can be soldered onto this
 | Primary usage | Alternate usage | 5V ok? | Bootloader? | Usage restriction (lock pin config)
PA0 | External GPIO or PWM or ADC5 | External open collector | Y
PA1 | External GPIO or PWM or ADC6 | External open collector | Y
PA2 | External GPIO or USART TX |  | Y | Pullup
PA3 | External GPIO or USART RX |  | N | Pullup
PA4 | External GPIO or DAC or ADC9 |  | N | Pulldown
PA5 | Relais 4 | Internal GPIO | N | Pulldown
PA6 | Internal GPIO (Motor2 R) |  | Y | Pulldown
PA7 | Internal GPIO (Motor2 F) |  | Y | Pulldown
PA8 | Backlight PWM |  | Y
PA9 | Relais 1 | Internal GPIO | Y
PA10 | Rs232 enable |  | Y
PA11 | USB - |  | Y | Pushpull | Alternate mode only
PA12 | USB + |  | Y | Pushpull | Alternate mode only
PA13 | LED1 red | Internal GPIO or STLINK | Y
PA14 | LED1 green | Internal GPIO or STLINK | Y
PA15 | Key left |  | Y |  | Input with pullup
PB0 | Internal GPIO (Motor1 R) |  | Y
PB1 | Internal GPIO (Motor1 F) |  | Y
PB2 | IR signal | Internal GPIO | Y |  | Input with pullup
PB3 | External GPIO or SPI1 SCK | STLINK DO | Y
PB4 | External GPIO or SPI1 MISO |  | Y
PB5 | External GPIO or SPI1 MOSI |  | Y
PB6 | RS232 TX by USART1 |  | Y
PB7 | RS232 RX by USART1 |  | Y |  | Input with alternate mode
PB8 | LED2 red | Internal GPIO | Y | Pullup
PB9 | Key right |  | Y | Pullup | Input with pullup
PB10 | ESP-01 RX by USART3 | Internal GPIO or USART3 RX | Y |  | If ESP-01 found, input with alternate mode
PB11 | ESP-01 TX by USART3 | Internal GPIO or USART3 TX | Y
PB12 | Relais 2 | Internal GPIO | Y | Pulldown
PB13 | SPI2 SCK for LCD, flash, touch | Internal GPIO or SPI2 SCK | Y | Pulldown
PB14 | SPI2 MISO for LCD, flash, touch | Internal GPIO or SPI2 MISO | Y | Pulldown | Input with alternate mode
PB15 | SPI2 MOSI for LCD, flash, touch | Internal GPIO or SPI2 MOSI | Y | Pulldown
PC0 | External GPIO or ADC1 or I2C | Touch screen chip select | Y
PC1 | External GPIO or ADC2 or I2C | LCD reset line | Y
PC2 | External GPIO or ADC3 | IR power enable | Y
PC3 | External GPIO or ADC4 |  | Y
PC4 | Flash chip select |  | Y
PC5 | ESP-01 power enable | Internal open collector high side | Y
PC6 | Relais 3 | Internal GPIO | Y
PC7 | LCD A0 | Internal GPIO | Y
PC8 | Key down | Internal GPIO | Y |  | Input with pullup
PC9 | LCD CS | Internal GPIO | Y
PC10 | SPI3 SCK to AVR |  | Y
PC11 | SPI3 MISO from AVR |  | Y | Pullup | Input
PC12 | SPI3 MOSI to AVR |  | Y
PC13 | Key up | Internal GPIO | Y |  | Input with pullup
PC14 | 32kHz crystal | Internal GPIO | Y
PC15 | 32kHz crystal | Internal GPIO | Y
PD2 | LED2 green | Internal GPIO | Y
PH0 | 8MHz crystal |  | Y
PH1 | 8MHz crystal |  | Y
PH3 | Boot pin, connected to PC11 |  | Y |  | Input

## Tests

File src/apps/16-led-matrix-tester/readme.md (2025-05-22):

Tests how a pulsed LED would look like.

You can set a duty cycle and frequency for up to three outputs.
These might be the RGB colors of a connected LED.

Outputs are PB3, PB4 and PB5 and the internal LED1.

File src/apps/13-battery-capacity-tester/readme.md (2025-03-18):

Discharges a batterie until the voltage drops below a defined minimum.

Then the discharged capacity is written to a log file.

Select an appropriate load resistor able to handle the heat and limit the current to 2A.

The selected resistor may be in the range of 0.5Ω to 20Ω.

If sink 1 is active, the LED1 lights green. Sink 2 uses the red light of LED1.

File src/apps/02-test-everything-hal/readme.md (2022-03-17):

Tests all the hardware.

Connect a serial converter to the RS232 port.

19200 baud, no flow control, 1 stop bit.

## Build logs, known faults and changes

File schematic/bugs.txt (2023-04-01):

Bugs in Version 1.0:

1. == While programming the AVR, the right button may not be pressed ==
   Otherwise SCK of the programmer is short to GND
   Workaround: Don't press the right button while programming, disconnect programmer before testing
   Next version: Put a resistor in the SCK line to J20
2. == The output of the temperature sensor is connected to a digital input ==
   Workaround: Remove D24, connect Pin 1 of TH20 (Temperature output) to PB5 (at J20 this is easy)
   Cut PB0 before it goes to TH20 and then make a connection of PB0 (again from J20) to the anode pad of D24.
   Next version: Switch PB5 and PB0.
3 == R31 needs to be a diode ==
   Otherwise the low resistance of U2 will drop the level of Q23 and Q24 to low, ending in those FETs to be always on.
   So the ARM could not be switched off while on battery power.
   A diode in a 0805 case can be soldered on the R31 easily
   Next version: Really add a diode here
4. == Too much ripple while charing ==
   C23 is too small, the maximum capacity available at 0805 is 22µF
   Next version: Use a 1208 footprint there
5. == Description on the PCB is at the wrong place ==
   The "only H7" description is next to C64, but should be next to C71
   Next version: Move description
6. == TL431B is difficult to get in low quantities ==
   No workaround planned
7. == Reset of LCD needs a pullup ==
   If JP50 is left open (no control by GPIO), the reset needs a pull up to the PerEnablePower signal.
   Workaround: Add a 10k pull up on the J50 connecter. Or close JP50 and use the GPIO.
   Next version: Allow adding a pullup resistor.
8. == Low and high speed crystals are switched ==
   Workaround: Solder a low speed crystal at the footprint of the highspeed crystal (Y60).
   And a high speed crystal at Y61.
   Next version: Fix footprint and reorder crystals.
9. == ESD Protection for some pins is not complete ==
   The ESD protection is for 5V inputs. But PA3 and PA4 only support an input of 3.3V.
10.== The ARM bootloader sets pins PA6, PB9 and PB14 as output with a high level ==
   = PB14 =
   PB14 drives then the IC U50 while its shut off, violating the maximum input voltage. The same would be true
   for a display with MISO pin.
   Several workarounds are possible, *one* needs to be selected:
   A: Never execute the DFU bootloader directly. The DFU bootloader may be called from a user program, with PB14 locked
      as input.
   B: If no display with a MISO pin is used (the 128x128 has none) and flash speed is not important,
      R53 can be replaced by a diode and the internal pullup for PB14 can be activated.
      Positive: Easy, no fixes on the PCB needed
      Negative: The SPI frequency for the flash is limited to approximately 250...500kHz.
      This workaround is integrated into the schematic.
      B1: Using option B and add some pull-down resistor to receive higher speeds. 4.7kΩ should work.
   C: The peripheral can always be supplied with power by adding a closed connection between pins 2 and 3 of Q50.
   D: Using option B, but cut the MISO pin on the display away
   B: Using option B, cut the PCB track and add another diode.
   Next version: Add two diodes in the MISO line and a pull-down resistor.
   = PB9 =
   Workaround: Add a resistor in the line between PB9 and D63. Can be done easily at the back side of the PCB.
   = PA6 =
   Take care what is connected at J62.
11.== Pin description for the LEDs is wrong on the PCB ==
   B12 needs to be A13
   D2  needs to be A14
   A13 needs to be B8
   A14 needs to be D2
12.== Power surge when starting ESP-01 module ==
   An additional 100µF cap on VCC is reccommend to avoid a huge power drop when enabling the wifi module.
   It can be added between TP12 and H2.
   C120 needs to be reduced to 4.7µF to avoid a power surge to less than 2V,
   which would result in the LCD to stop displaying an image.

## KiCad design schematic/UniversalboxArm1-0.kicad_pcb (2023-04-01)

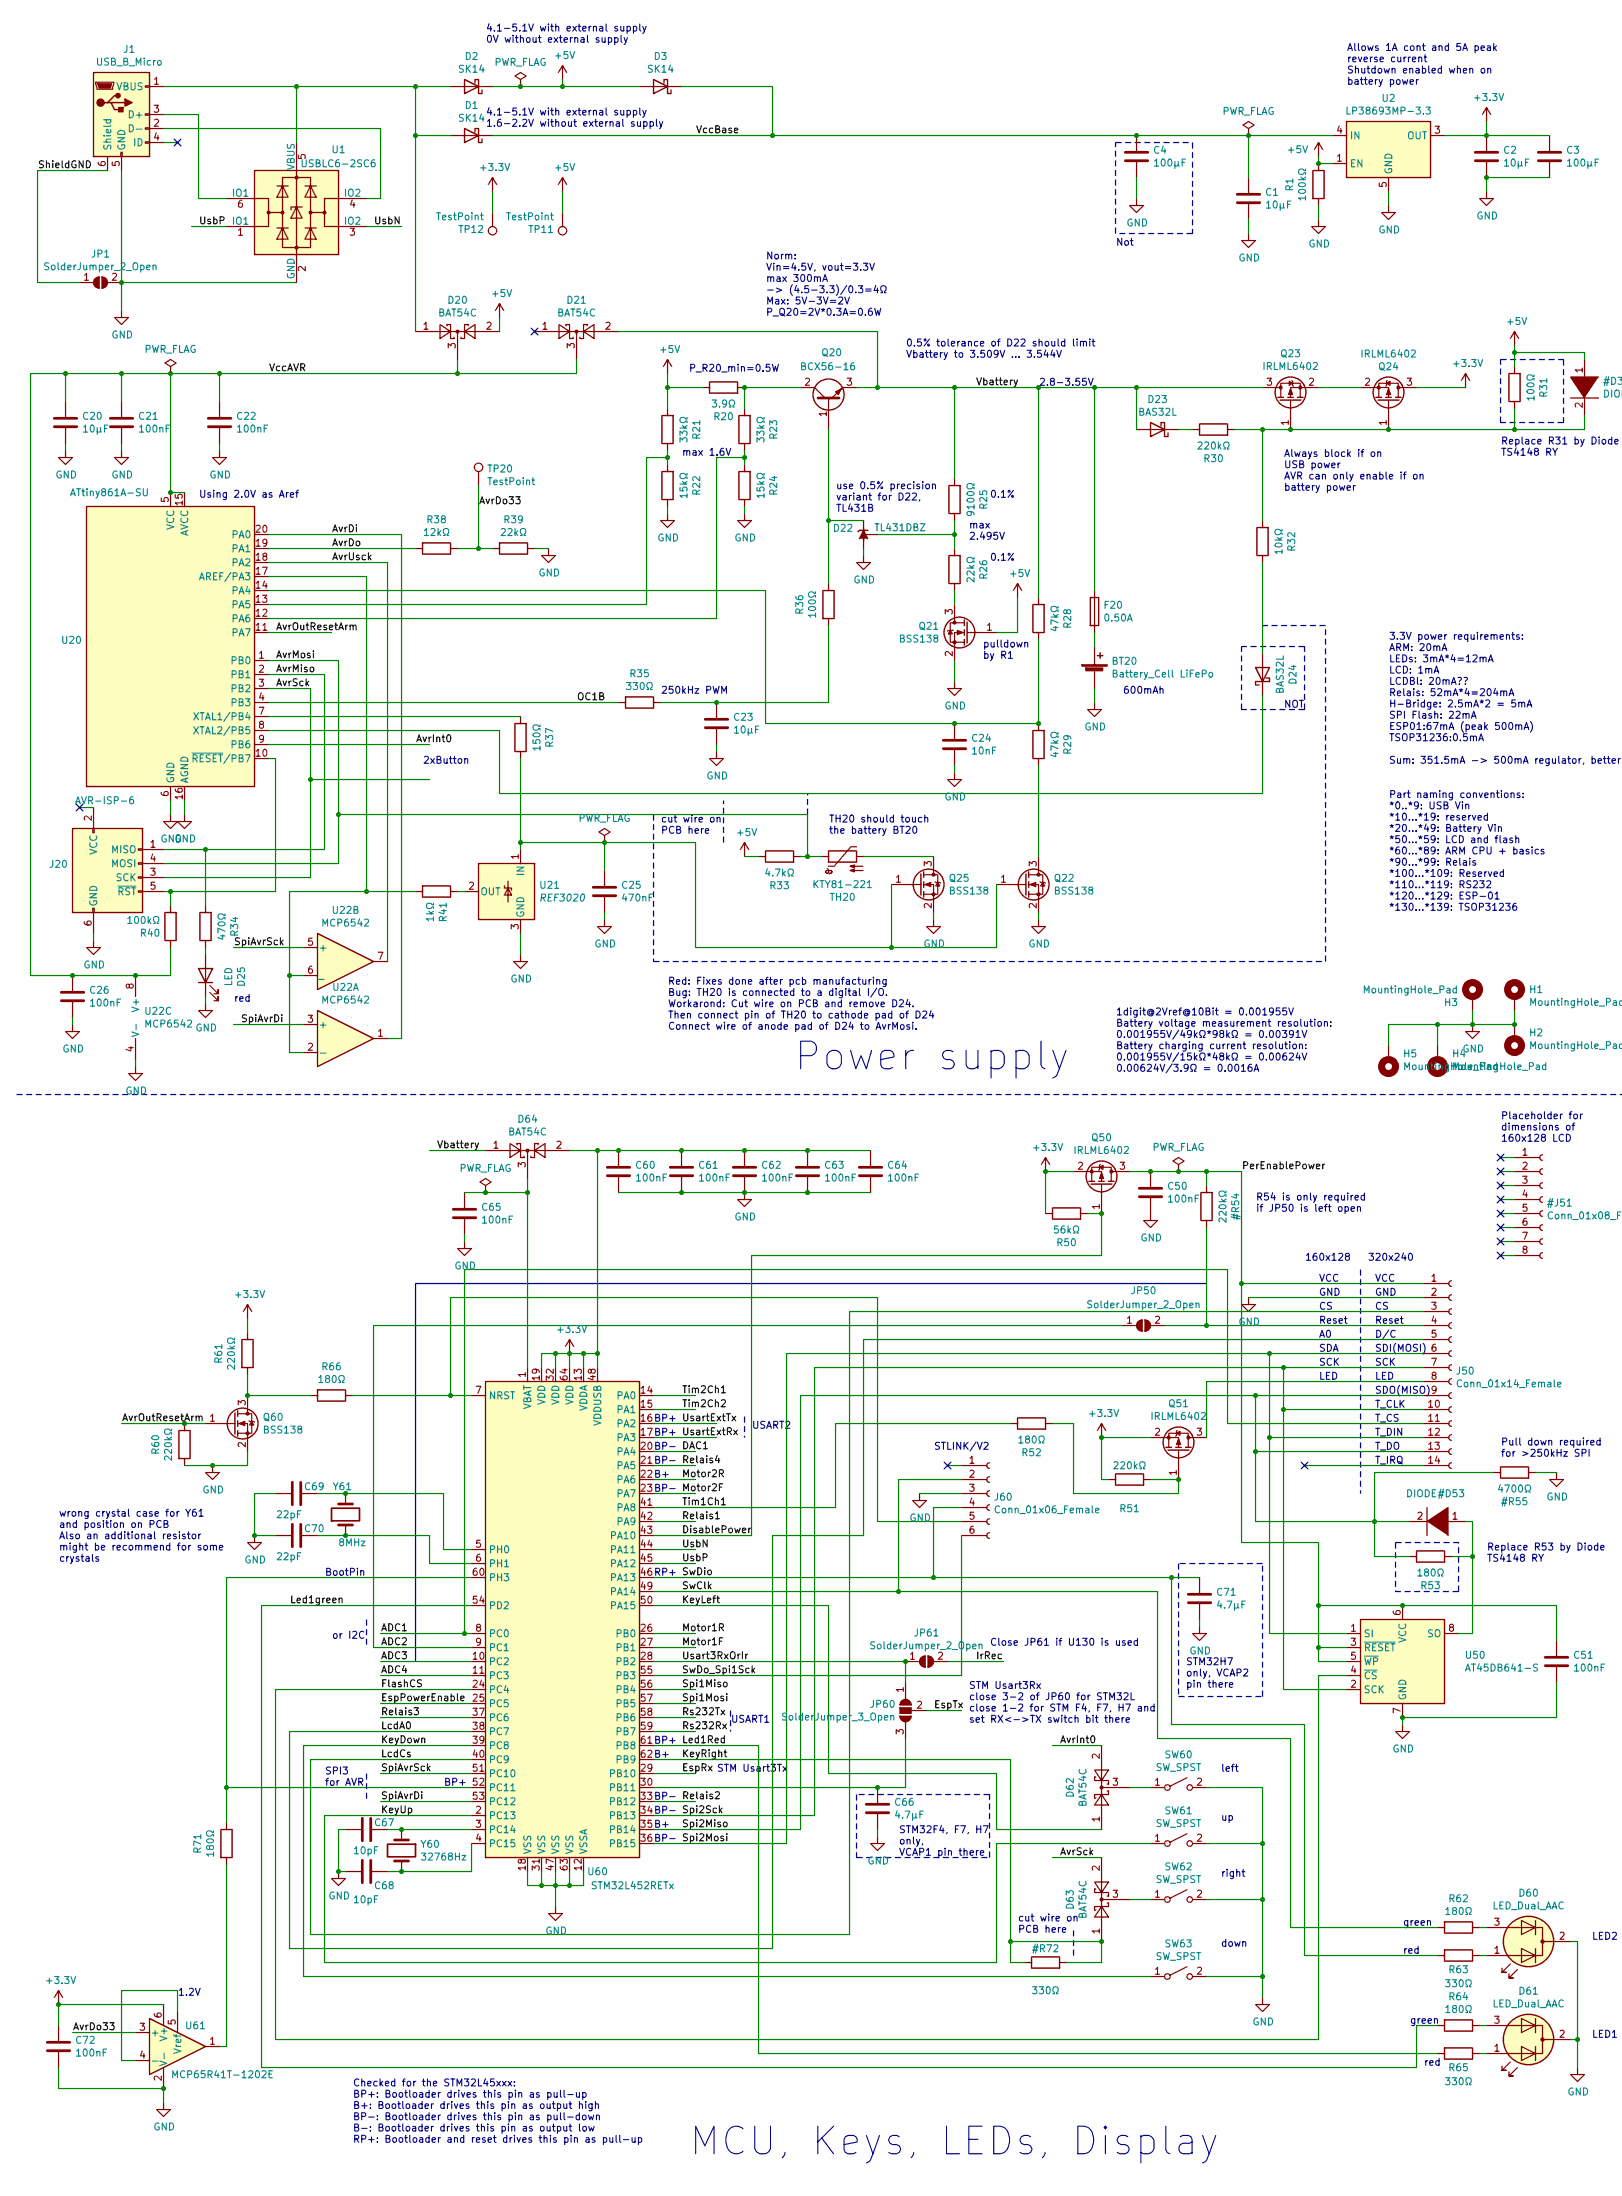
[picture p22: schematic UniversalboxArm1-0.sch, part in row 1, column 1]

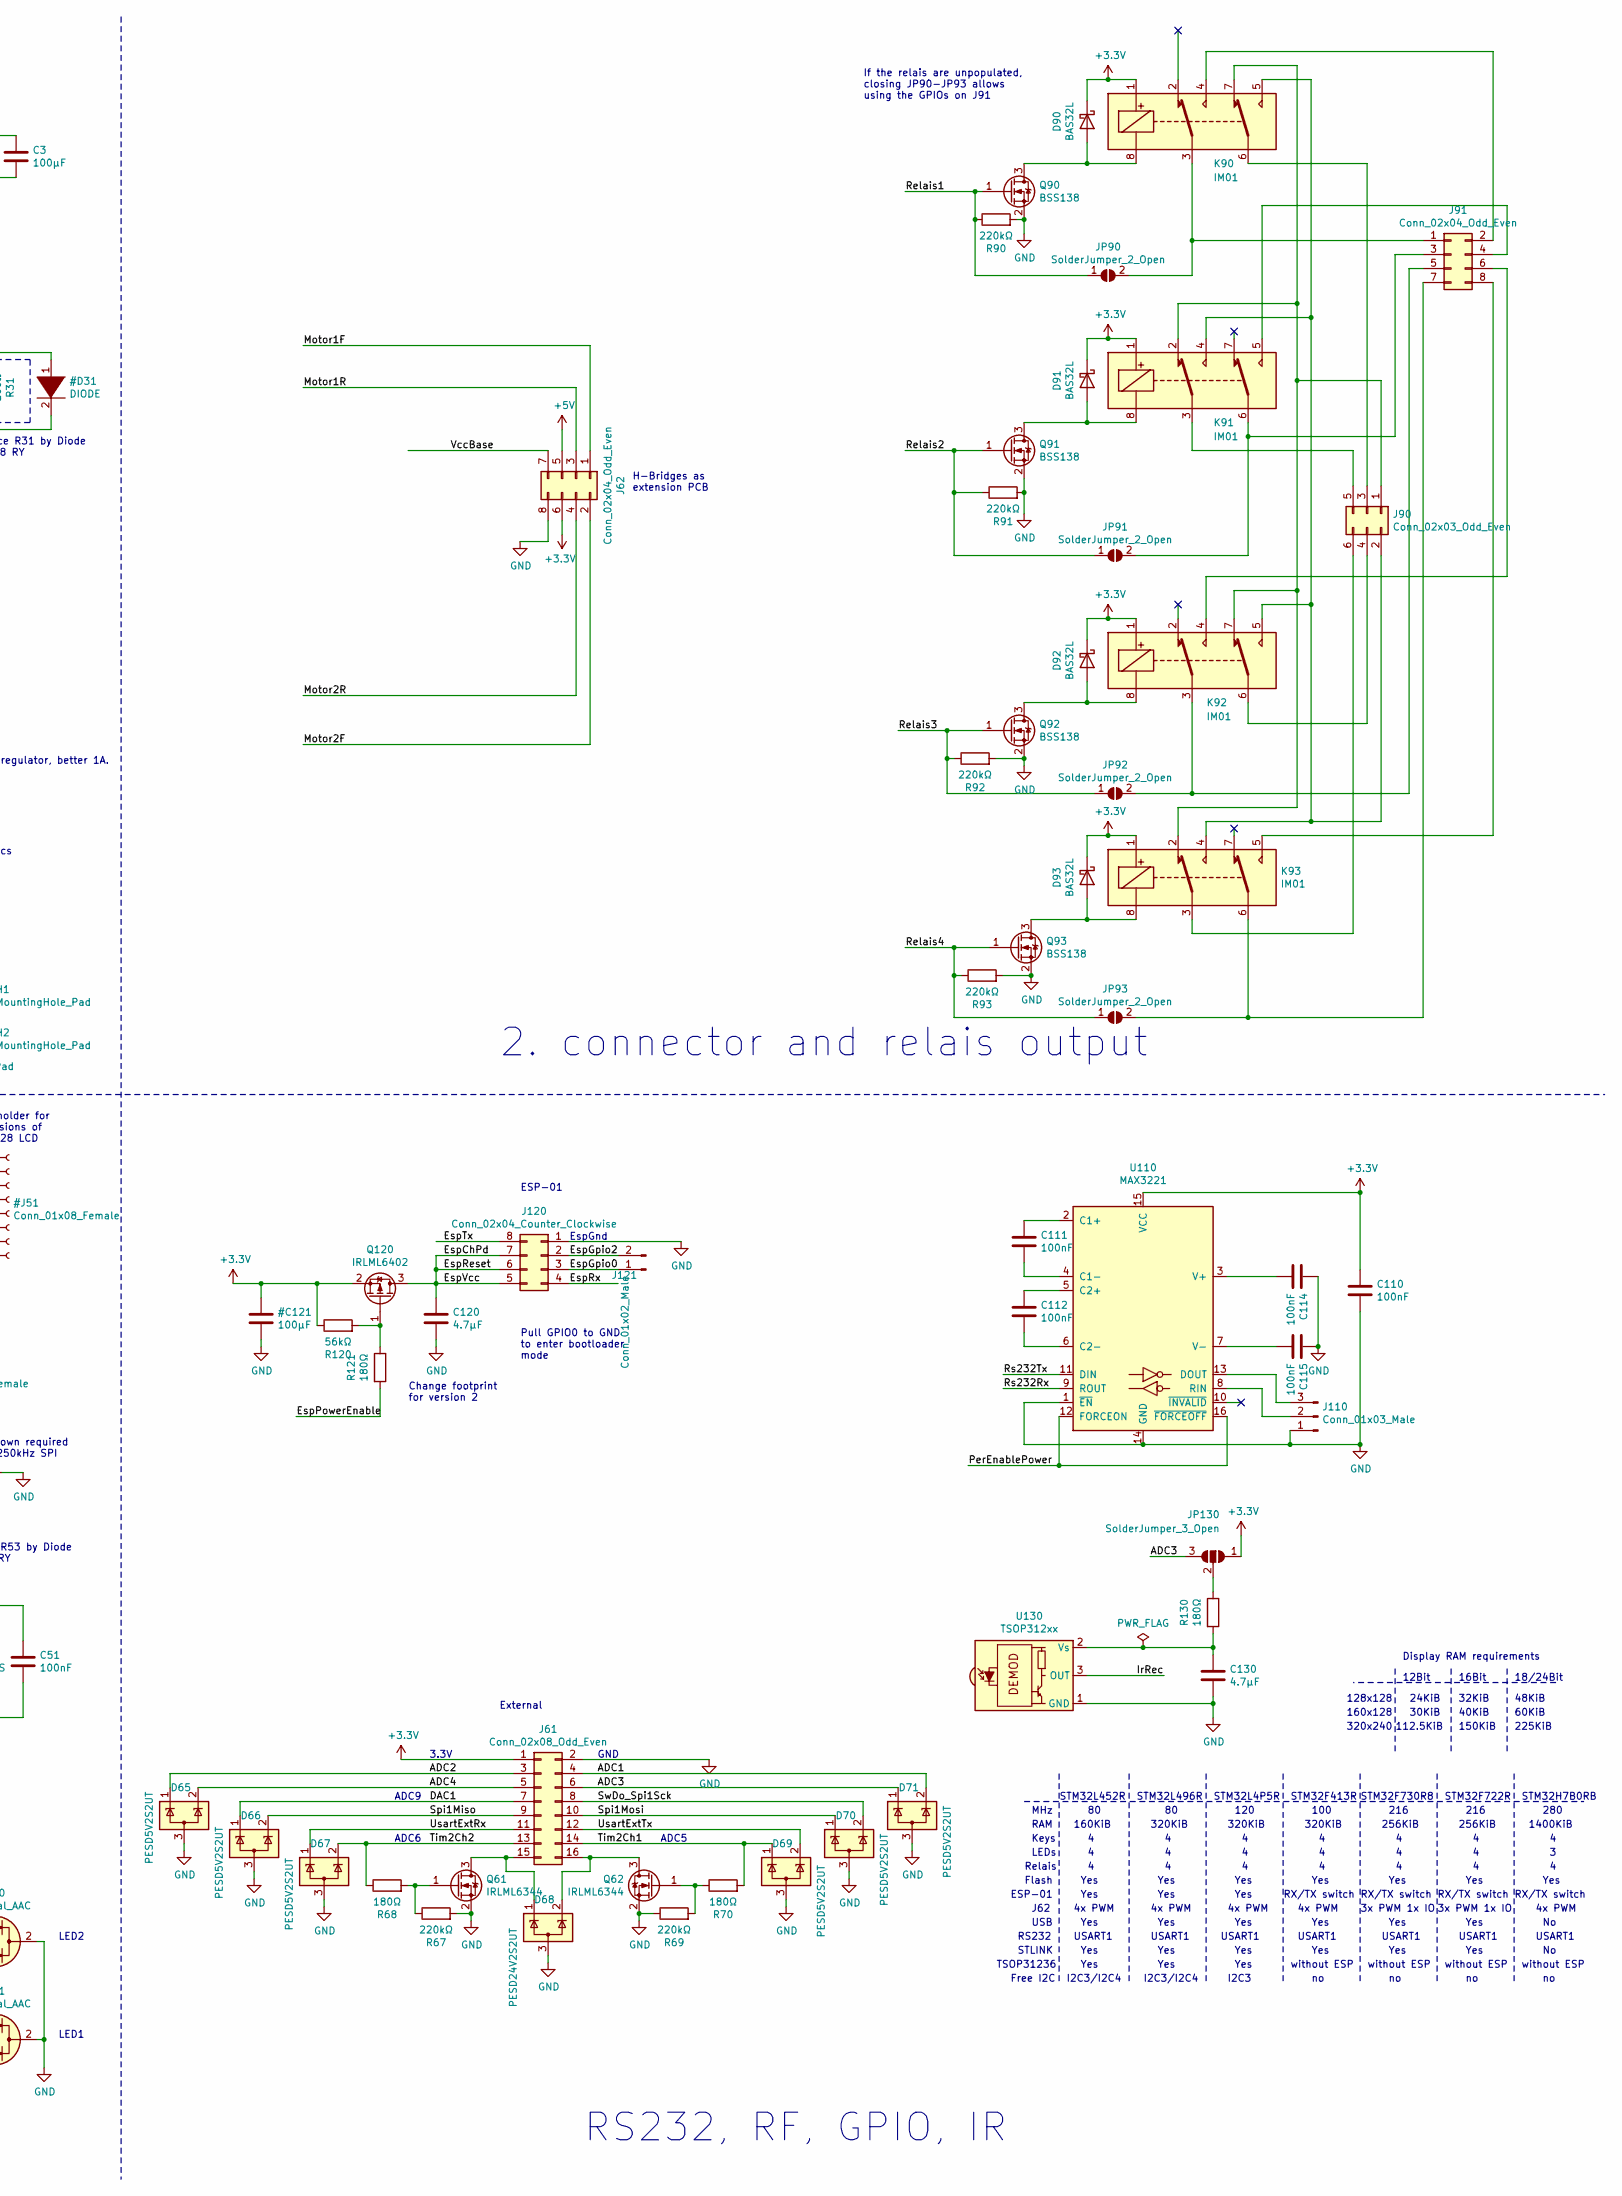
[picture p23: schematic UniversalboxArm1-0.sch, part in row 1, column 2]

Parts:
BT20: Battery_Cell LiFePo; Keystone_Holder_1xAA_1015
C1, C2, C20, C23: 10µF; C_0805_2012Metric_Pad1.15x1.40mm_HandSolder
C3, C4: 100µF; C_1206_3216Metric_Pad1.33x1.80mm_HandSolder
C21, C22, C26, C50, C51, C60, C61, C62, C63, C64, C65, C72, C110, C111, C112, C114, C115: 100nF; C_0805_2012Metric_Pad1.15x1.40mm_HandSolder
C24: 10nF; C_0805_2012Metric_Pad1.15x1.40mm_HandSolder
C25: 470nF; C_0805_2012Metric_Pad1.15x1.40mm_HandSolder
C66, C71, C130: 4.7µF; C_0805_2012Metric_Pad1.15x1.40mm_HandSolder
C67, C68: 10pF; C_0805_2012Metric_Pad1.15x1.40mm_HandSolder
C69, C70: 22pF; C_0805_2012Metric_Pad1.15x1.40mm_HandSolder
C120: 4.7µF; C_1206_3216Metric_Pad1.33x1.80mm_HandSolder
D1, D2, D3: SK14; D_SMA
D20, D21, D62, D63, D64: BAT54C; SOT-23
D22: TL431DBZ; SOT-23
D23, D24, D90, D91, D92, D93: BAS32L; D_MiniMELF
D25: LED; LED_D3.0mm
D60, D61: LED_Dual_AAC; LED_D3.0mm-3
D65, D66, D67, D69, D70, D71: PESD5V2S2UT; SOT-23
D68: PESD24V2S2UT; SOT-23
F20: 0.50A; SFM_OMNI-BLOK_Handsolder
H1, H2, H3, H4, H5: MountingHole_Pad; MountingHole_3.2mm_M3_Pad
J1: USB_B_Micro; USB_Micro-B_Amtek-MIUSB-F5M-BBX-U_Handsolder
J20: AVR-ISP-6; PinHeader_2x03_P2.54mm_Vertical
J50: Conn_01x14_Female; LCD_320x240_2.4
J60: Conn_01x06_Female; PinHeader_1x06_P2.54mm_Vertical
J61: Conn_02x08_Odd_Even; PinHeader_2x08_P2.54mm_Vertical
J62, J91: Conn_02x04_Odd_Even; PinHeader_2x04_P2.54mm_Vertical
J90: Conn_02x03_Odd_Even; PinHeader_2x03_P2.54mm_Vertical
J110: Conn_01x03_Male; PinHeader_1x03_P2.54mm_Vertical
J120: Conn_02x04_Counter_Clockwise; PinSocket_ESP-01
J121: Conn_01x02_Male; PinHeader_1x02_P2.54mm_Vertical
JP1, JP50, JP61, JP90, JP91, JP92, JP93: SolderJumper_2_Open; SolderJumper-2_P1.3mm_Open_RoundedPad1.0x1.5mm
JP60, JP130: SolderJumper_3_Open; SolderJumper-3_P1.3mm_Open_RoundedPad1.0x1.5mm
K90, K91, K92, K93: IM01; Relay_DPDT_Omron_G6K-2F-Y
Q20: BCX56-16; SOT-89-3
Q21, Q22, Q25, Q60, Q90, Q91, Q92, Q93: BSS138; SOT-23
Q23, Q24, Q50, Q51, Q120: IRLML6402; SOT-23
Q61, Q62: IRLML6344; SOT-23
R1, R40: 100kΩ; R_0805_2012Metric_Pad1.15x1.40mm_HandSolder
R20: 3.9Ω; R_MELF_MMB-0207
R21, R23: 33kΩ; R_0805_2012Metric_Pad1.15x1.40mm_HandSolder
R22, R24: 15kΩ; R_0805_2012Metric_Pad1.15x1.40mm_HandSolder
R25: 9100Ω; R_0805_2012Metric_Pad1.15x1.40mm_HandSolder
R26, R39: 22kΩ; R_0805_2012Metric_Pad1.15x1.40mm_HandSolder
R28, R29: 47kΩ; R_0805_2012Metric_Pad1.15x1.40mm_HandSolder
R30, R51, R60, R61, R67, R69, R90, R91, R92, R93: 220kΩ; R_0805_2012Metric_Pad1.15x1.40mm_HandSolder
R31, R36: 100Ω; R_0805_2012Metric_Pad1.15x1.40mm_HandSolder
R32: 10kΩ; R_0805_2012Metric_Pad1.15x1.40mm_HandSolder
R33: 4.7kΩ; R_0805_2012Metric_Pad1.15x1.40mm_HandSolder
R34: 470Ω; R_0805_2012Metric_Pad1.15x1.40mm_HandSolder
R35, R63, R65: 330Ω; R_0805_2012Metric_Pad1.15x1.40mm_HandSolder
R37: 150Ω; R_0805_2012Metric_Pad1.15x1.40mm_HandSolder
R38: 12kΩ; R_0805_2012Metric_Pad1.15x1.40mm_HandSolder
R41: 1kΩ; R_0805_2012Metric_Pad1.15x1.40mm_HandSolder
R50, R120: 56kΩ; R_0805_2012Metric_Pad1.15x1.40mm_HandSolder
R52, R53, R62, R64, R66, R68, R70, R71, R121, R130: 180Ω; R_0805_2012Metric_Pad1.15x1.40mm_HandSolder
SW60, SW61, SW62, SW63: SW_SPST; SW_PUSH_6mm_H13mm
TH20: KTY81-221; TO-92-2
TP11, TP12, TP20: TestPoint; TestPoint_THTPad_D1.5mm_Drill0.7mm
U1: USBLC6-2SC6; SOT-23-6
U2: LP38693MP-3.3; SOT-223-5
U20: ATtiny861A-SU; SOIC-20W_7.5x12.8mm_P1.27mm
U21: REF3020; SOT-23
U22: MCP6542; SOIC-8_3.9x4.9mm_P1.27mm
U50: AT45DB641-S; SO-8_5.3x6.2mm_P1.27mm
U60: STM32L452RETx; LQFP-64_10x10mm_P0.5mm_Handsoldering
U61: MCP65R41T-1202E; SOT-23-6_Handsoldering
U110: MAX3221; SSOP-16_5.3x6.2mm_P0.65mm_Handsolder
U130: TSOP312xx; Vishay_CAST-3Pin
Y60: 32768Hz; Crystal_HC49-U_Vertical
Y61: 8MHz; Crystal_MP03

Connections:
/ADC1: D71.2 (K), J50.11, J61.4, U60.8 (PC0)
/ADC2: D65.1 (K), J61.3, JP50.1 (A), U60.9 (PC1)
/ADC3: D71.1 (K), J61.6, JP130.3 (B), U60.10 (PC2)
/ADC4: D65.2 (K), J61.5, U60.11 (PC3)
/AvrDi: U20.20 (PA0), U22.1
/AvrDo: R38.2, U20.19 (PA1)
/AvrDo33: R38.1, R39.2, TP20.1, U61.3 (+)
/AvrInt0: D62.2, U20.9 (PB6)
/AvrMiso: J20.1 (MISO), R34.2, U20.2 (PB1)
/AvrMosi: J20.4 (MOSI), R33.2, TH20.1, U20.1 (PB0)
/AvrOutResetArm: Q60.1 (G), R60.1, U20.11 (PA7)
/AvrSck: D63.2, J20.3 (SCK), U20.3 (PB2)
/AvrUsck: U20.18 (PA2), U22.7
/DAC1: D66.1 (K), J61.7, U60.20 (PA4)
/DisablePower: Q50.1 (G), R50.2, U60.43 (PA10)
/EspChPd: C120.1, J120.5, J120.6, J120.7, Q120.3 (D)
/EspGpio0: J120.3, J121.1
/EspGpio2: J120.2, J121.2
/EspPowerEnable: R121.2, U60.25 (PC5)
/EspRx: J120.4, U60.29 (PB10)
/EspTx: J120.8, JP60.2 (C)
/FlashCS: U50.4 (~CS), U60.24 (PC4)
/IrRec: JP61.2 (B), U130.3 (OUT)
/KeyDown: SW63.1 (A), U60.39 (PC8)
/KeyLeft: D62.1, U60.50 (PA15)
/KeyRight: D63.1, U60.62 (PB9)
/KeyUp: SW61.1 (A), U60.2 (PC13)
/LcdA0: J50.5, U60.38 (PC7)
/LcdCs: J50.3, U60.40 (PC9)
/Led1Red: R65.2, U60.61 (PB8)
/Led1green: R64.2, U60.54 (PD2)
/Motor1F: J62.1, U60.27 (PB1)
/Motor1R: J62.3, U60.26 (PB0)
/Motor2F: J62.2, U60.23 (PA7)
/Motor2R: J62.4, U60.22 (PA6)
/OC1B: R35.2, U20.4 (PB3)
/Relais1: JP90.1 (A), Q90.1 (G), R90.1, U60.42 (PA9)
/Relais2: JP91.1 (A), Q91.1 (G), R91.1, U60.33 (PB12)
/Relais3: JP92.1 (A), Q92.1 (G), R92.1, U60.37 (PC6)
/Relais4: JP93.1 (A), Q93.1 (G), R93.1, U60.21 (PA5)
/Rs232Rx: U60.59 (PB7), U110.9 (ROUT)
/Rs232Tx: U60.58 (PB6), U110.11 (DIN)
/ShieldGND: J1.6 (Shield), JP1.1 (A)
/Spi1Miso: D66.2 (K), J61.9, U60.56 (PB4)
/Spi1Mosi: D70.1 (K), J61.10, U60.57 (PB5)
/Spi2Mosi: J50.6, J50.12, U50.1 (SI), U60.36 (PB15)
/Spi2Sck: J50.7, J50.10, U50.2 (SCK), U60.34 (PB13)
/SpiAvrDi: U22.3 (+), U60.53 (PC12)
/SpiAvrSck: U22.5 (+), U60.51 (PC10)
/SwClk: J60.2, R62.2, U60.49 (PA14)
/SwDio: C71.1, J60.4, R63.2, U60.46 (PA13)
/SwDo_Spi1Sck: D70.2 (K), J60.6, J61.8, U60.55 (PB3)
/Tim1Ch1: R52.1, U60.41 (PA8)
/Tim2Ch1: D69.1 (K), J61.14, R70.2, U60.14 (PA0)
/Tim2Ch2: D67.2 (K), J61.13, R68.1, U60.15 (PA1)
/Usart3RxOrIr: JP60.1 (A), JP61.1 (A), U60.28 (PB2)
/UsartExtRx: D67.1 (K), J61.11, U60.17 (PA3)
/UsartExtTx: D69.2 (K), J61.12, U60.16 (PA2)
/UsbN: U1.3 (IO2), U60.44 (PA11)
/UsbP: U1.1 (IO1), U60.45 (PA12)
/Vbattery: D21.2, D23.2 (A), D64.1, F20.1, Q20.3 (E), Q23.3 (D), R25.2, R28.2
/VccAVR: C20.1, C21.1, C22.1, C26.1, D20.3, D21.3, R40.1, U20.5 (VCC), U20.15 (AVCC), U22.8 (V+)
/VccBase: C1.1, C4.1, D1.1 (K), D3.1 (K), J62.7, U2.4 (IN)
unnamed: BT20.1 (+), F20.2
unnamed: C23.1, R35.1, R36.2
unnamed: C24.1, R28.1, R29.2, U20.14 (PA4)
unnamed: C25.1, Q22.1 (G), Q25.1 (G), R37.1, U21.1 (IN)
unnamed: C65.1, D64.3, U60.1 (VBAT)
unnamed: C66.1, JP60.3 (B), U60.30 (PB11)
unnamed: C67.1, U60.3 (PC14), Y60.1
unnamed: C68.1, U60.4 (PC15), Y60.2
unnamed: C69.1, U60.5 (PH0), Y61.2
unnamed: C70.1, U60.6 (PH1), Y61.1
unnamed: C111.1, U110.2 (C1+)
unnamed: C111.2, U110.4 (C1-)
unnamed: C112.1, U110.5 (C2+)
unnamed: C112.2, U110.6 (C2-)
unnamed: C114.2, U110.3 (V+)
unnamed: C115.2, U110.7 (V-)
unnamed: C130.1, R130.2, U130.2 (Vs)
unnamed: D1.2 (A), D2.2 (A), D20.1, J1.1 (VBUS), U1.5 (VBUS)
unnamed: D22.1 (K), Q20.1 (B), R36.1
unnamed: D22.2 (REF), R25.1, R26.2
unnamed: D23.1 (K), R30.1
unnamed: D24.1 (K), U20.8 (XTAL2/PB5)
unnamed: D24.2 (A), R32.1
unnamed: D25.2 (A), R34.1
unnamed: D60.1 (A1), R63.1
unnamed: D60.3 (A2), R62.1
unnamed: D61.1 (A1), R65.1
unnamed: D61.3 (A2), R64.1
unnamed: D62.3, SW60.1 (A)
unnamed: D63.3, SW62.1 (A)
unnamed: D68.1 (K), J61.15, Q61.3 (D)
unnamed: D68.2 (K), J61.16, Q62.3 (D)
unnamed: D90.2 (A), K90.8, Q90.3 (D)
unnamed: D91.2 (A), K91.8, Q91.3 (D)
unnamed: D92.2 (A), K92.8, Q92.3 (D)
unnamed: D93.2 (A), K93.8, Q93.3 (D)
unnamed: J1.2 (D-), U1.4 (IO2)
unnamed: J1.3 (D+), U1.6 (IO1)
unnamed: J20.5 (~RST), R40.2, U20.10 (~RESET~/PB7)
unnamed: J50.8, Q51.3 (D)
unnamed: J60.5, R66.1, U60.7 (NRST)
unnamed: J90.1, K90.7, K91.2, K92.7, K93.2
unnamed: J90.2, K90.5, K91.4, K92.5, K93.4
unnamed: J90.3, K90.6
unnamed: J90.4, K92.6
unnamed: J90.5, K91.3
unnamed: J90.6, K93.3
unnamed: J91.1, JP90.2 (B), K90.3
unnamed: J91.2, K90.4
unnamed: J91.3, JP91.2 (B), K91.6
unnamed: J91.4, K91.5
unnamed: J91.5, JP92.2 (B), K92.3
unnamed: J91.6, K92.4
unnamed: J91.7, JP93.2 (B), K93.6
unnamed: J91.8, K93.5
unnamed: J110.2, U110.8 (RIN)
unnamed: J110.3, U110.13 (DOUT)
unnamed: JP130.2 (C), R130.1
unnamed: Q20.2 (C), R20.2, R23.2
unnamed: Q21.3 (D), R26.1
unnamed: Q22.3 (D), R29.1
unnamed: Q23.2 (S), Q24.2 (S)
unnamed: Q25.3 (D), TH20.2
unnamed: Q51.1 (G), R51.2, R52.2
unnamed: Q60.3 (D), R61.2, R66.2
unnamed: Q61.1 (G), R67.1, R68.2
unnamed: Q62.1 (G), R69.2, R70.1
unnamed: Q120.1 (G), R120.2, R121.1
unnamed: R21.1, R22.2, U20.13 (PA5)
unnamed: R23.1, R24.2, U20.12 (PA6)
unnamed: R37.2, U20.7 (XTAL1/PB4)
unnamed: R41.1, U21.2 (OUT)
unnamed: R41.2, U20.17 (AREF/PA3), U22.2 (-), U22.6 (_)
unnamed: R71.1, U60.52 (PC11), U60.60 (PH3)
unnamed: R71.2, U61.1
unnamed: U61.4 (-), U61.5 (Vref)

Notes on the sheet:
600mAh
3.3V power requirements: ARM: 20mA LEDs: 3mA*4=12mA LCD: 1mA LCDBl: 20mA?? Relais: 52mA*4=204mA H-Bridge: 2.5mA*2 = 5mA SPI Flash: 22mA ESP01:67mA (peak 500mA) TSOP31236:0.5mA Sum: 351.5mA -> 500mA regulator, better 1A.
250kHz PWM
4.1-5.1V with external supply 0V without external supply
2.8-3.55V
Norm: Vin=4.5V, vout=3.3V max 300mA -> (4.5-3.3)/0.3=4Ω Max: 5V-3V=2V P_Q20=2V*0.3A=0.6W
Always block if on USB power AVR can only enable if on battery power
use 0.5% precision variant for D22, TL431B
max 2.495V
Allows 1A cont and 5A peak reverse current Shutdown enabled when on battery power
4.1-5.1V with external supply 1.6-2.2V without external supply
Using 2.0V as Aref
TH20 should touch the battery BT20
red
P_R20_min=0.5W
2xButton
max 1.6V
1digit@2Vref@10Bit = 0.001955V Battery voltage measurement resolution: 0.001955V/49kΩ*98kΩ = 0.00391V Battery charging current resolution: 0.001955V/15kΩ*48kΩ = 0.00624V 0.00624V/3.9Ω = 0.0016A
Power supply
2. connector and relais output
left
right
down
pulldown by R1
STM32F4, F7, H7 only, VCAP1 pin there
Placeholder for dimensions of 160x128 LCD
SPI3 for AVR
320x240
160x128
VCC
GND
Reset
SDA
SCK
LED
D/C
SDI(MOSI)
SDO(MISO)
T_CLK
T_CS

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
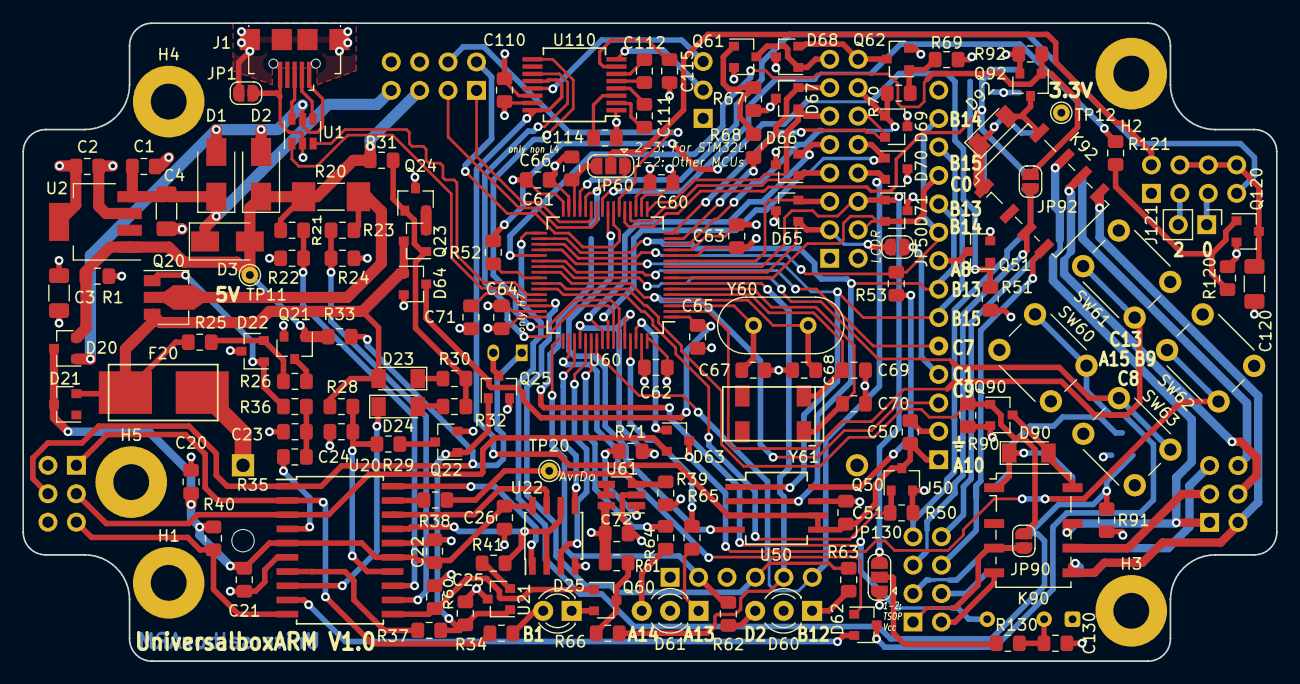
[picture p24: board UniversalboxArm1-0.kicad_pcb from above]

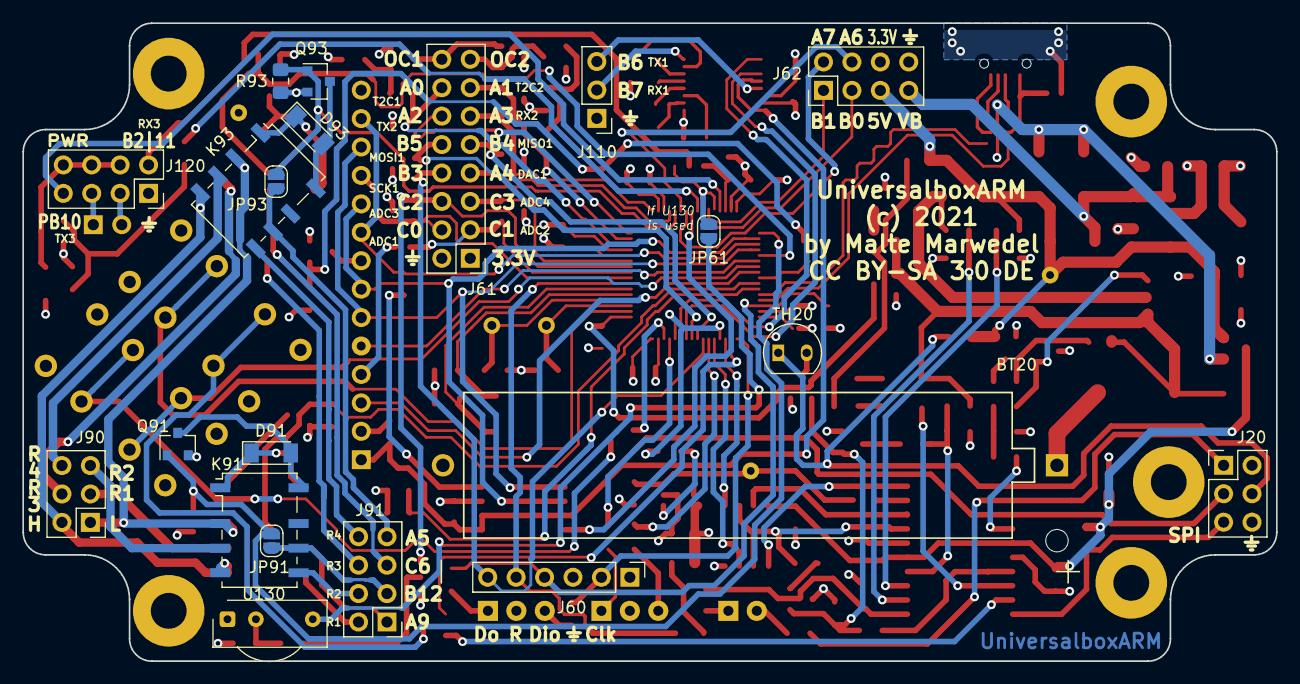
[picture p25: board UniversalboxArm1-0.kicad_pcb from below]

Board: 4 copper layers, 112.0 x 57.0 mm, 170 parts (21 on the bottom side), 147 nets.

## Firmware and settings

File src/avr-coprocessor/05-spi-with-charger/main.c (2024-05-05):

/*UniversalboxARM - AVR coprocessor
  (c) 2021-2022, 2024 by Malte Marwedel
  www.marwedels.de/malte

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
  Features:
  Implementation to reset the ARM and select the boot mode
  Hold down the right key by 1s to toggle the boot pin
  Hold down the left key by 1s to generate a reset.
  When running on battery:
  Hold down the left key and than the right key at the same time by 1s to power
    down the ARM.
  Hold down the right and left at the same time to power up the ARM.
  Also allows communication with ARM processor over SPI.
  And adds charger control logic for the LiFePo cell.

  The following commands are supported:
  All written in coprocCommands.h

  The minimum clock of the SPI is 10Hz, the maximum ~1kHz.
  If there is no clock for 150ms, the SPI resets its state to the first bit.
  If a write command (beginning with 0x80) has been sent, there should be a
  delay of at least 20ms until the next write command is sent.

  The LED signals:
  1s on on power-on to signal operation
  Two short flashes to signal setting the boot option to bootloader mode
       (high pin)
  One short flash to signal setting the boot option to normal boot (low pin)
  LED gets on after holding the left key for 1s, the reset pin is released as
  soon as the button is released.
  If the battery is charging, the LED is inverted. So it lights up when charged
  and flashes off when pressing the keys or running SPI commands.

  Pin connection:
  PINA.0 = Input, AVR DI
  PINA.1 = Output, AVR DO and boot pin state (high state = bootloader)
  PINA.2 = Input, AVR SCK
  PINA.3 = Input, AREF
  PINA.4 = Input, Battery voltage measurement
  PINA.5 = Input, Vcc measurement
  PINA.6 = Input, Voltage drop for charge current measurement
  PINA.7 = Output, pull high to set ARM into reset state.
  PINB.0 = With PCB fix: pull down to power the ARM by battery. (MOSI for ISP)
         = Without PCB fix: Input, Non working battery temperature measurement (MOSI for ISP)
  PINB.1 = Output, User LED (MISO for ISP)
  PINB.2 = Input with pullup, right key (SCK for ISP)
  PINB.3 = Output, PWM for battery charging (OC1B). Set to 0V to disable charging
  PINB.4 = Output, Power save option, set high to enable temperature and battery
                   voltage measurement, low disconnects the voltage dividers
  PINB.5 = With PCB Fix: Input, battery temperature measurement
           Without PC fix: Output, pull down to power the ARM by battery.
  PINB.6 = Input with pullup, left key (allows wakeup from power down by Int0)
           If workaround for temperature sensor is applied: Input without pullup,
           temperature sensor can be read as long as key is not pressed
  PINB.7 = reset pin

  Set F_CPU to 128kHz and the fuses to use the internal 128kHz oscillator.

  WARNING: While an ISP programmer is connected, the right button may not be
           pressed, as this would short circuit SCK of the programmer to ground.
           With the workaround for the temperature sensor, the same is true for
           the left button too.

Current consumption when idle sleep mode (wakeup every 10ms) @ 3.3V
360-380µA, which splits up:
--> 285µA at R25 with D22 -> can not be fixed in software
--> 1.7µA at R28 -> acceptable
-->   9nA at R30 -> acceptable
--> 0.5µA at D64 -> For RTC of ARM, as intended
--> 86-110µA at D21
---->    1.2µA for comparator U22
----> 90-110µA consumption of the AVR
------> 11µA for oscillator
------> 18µA for the brown out detector


Current consumption when in power down mode @ 2.4V (simulate with 2x NIMH battery)
200µA
--> 200µA at R25 with D22 -> can not be fixed in software
Everything else nearly needs no power at all.

*/

#include <stdlib.h>
#include <stdint.h>
#include <string.h>
#include <stdbool.h>

#include <avr/eeprom.h>
#include <util/crc16.h>

#include "hardware.h"
#include "timing.h"
#include "spi.h"
#include "coprocCommands.h"
#include "chargerStatemachine.h"

#define VCC_CONNECTED 3200

typedef struct {
	uint8_t chargerError;
	uint32_t chargingCycles;
	uint32_t prechargingCycles;
	uint64_t chargingSumAllTimes; //[mAms]
	uint32_t opTotal; //time in [minutes]
	uint16_t crc; //must be the last in the struct
} persistent_t;

persistent_t EEMEM g_settingsEepromA;

//some space holder, so the delete - write algorithm does only operate on one copy
uint32_t EEMEM g_eepromDummy;

persistent_t EEMEM g_settingsEepromB;

static uint16_t CrcCalc(const uint8_t * input, size_t len) {
	uint16_t crc = 0xFFFF;
	for (size_t i = 0; i < len; i++) {
		crc = _crc16_update(crc, input[i]);
	}
	return crc;
}

static bool SettingsLoadSub(persistent_t * pSettings, persistent_t * pSource) {
	eeprom_read_block(pSettings, pSource, sizeof(persistent_t));
	uint16_t crc = CrcCalc((uint8_t *)pSettings, sizeof(persistent_t) - sizeof(uint16_t));
	if (pSettings->crc == crc) {
		return true;
	}
	return false;
}

static void SettingsLoad(persistent_t * pSettings) {
	if (!SettingsLoadSub(pSettings, &g_settingsEepromA)) {
		if (!SettingsLoadSub(pSettings, &g_settingsEepromB)) {
			memset(pSettings, 0, sizeof(persistent_t));
		}
	}
}

static void SettingsSave(persistent_t * pSettings) {
	uint16_t crc = CrcCalc((uint8_t *)pSettings, sizeof(persistent_t) - sizeof(uint16_t));
	pSettings->crc = crc;
	eeprom_update_block(pSettings, &g_settingsEepromA, sizeof(persistent_t));
	eeprom_update_block(pSettings, &g_settingsEepromB, sizeof(persistent_t));
}

//just switch everything off
static void DeepDischargePrevention(void) {
	SensorsOff();
	AdPowerdown();
	TimerStop();
	PinsWakeupByKeyPressOn();
	WatchdogDisable();
	WaitForExternalInterrupt(); //get out by a keypress only
	PinsWakeupByKeyPressOff(); //must be called before SPI is enabled again
	HardwareInit();
	TimerInit(true);
	TimerSlow();
}

/*if alarm is non 0, its a timeout in [s] until a wakeup of the ARM CPU occurs
  after the return of the function, reinitSpiDelay should be set
  The return value tells the reason for the wakeup:
  0: undefined
  1: wakeup by alarm
  2: wakeup by USB power applied
  3: wakeup by user keypress
*/

static uint8_t PowerDownLoop(uint16_t alarm) {
	uint8_t checkInputVoltage = 0;
	uint8_t checkBatteryVoltage = 0;
	uint8_t checkAlarm = 0;
	//we must first release the keys, otherwise the power up will be instantly follow a power down
	uint8_t powerByKeyState = 0;
	uint8_t wakeupReason = 0;
	PwmBatterySet(0);
	SpiDisable();
	SensorsOff();
	ArmReset();
	ArmUserprog(); //must be set low, before battery is powered off!
	ArmBatteryOff();
	waitms(10); //make sure ARM finally is in reset state and capacitors are discharged
	ArmRun(); //the low level saves some power, so we do not drive against the pull-down resistor.
	LedOff();
	PinsPowerdown(); //we only need the key inputs, HardwareInit() will set the configuration back
	TimerSlow();
	while (1) { //loop runs every 100ms
		//wakeup by input voltage -> USB powered
		if (checkInputVoltage == 0) { //check every 500ms
			checkInputVoltage = 5;
			SensorsOn();
			waitms(1);
			uint16_t inputVoltage = SensorsInputvoltageGet();
			if (inputVoltage >= VCC_CONNECTED) {
				wakeupReason = 2;
				break;
			}
			if (checkBatteryVoltage == 0) { //check every 10s
				checkBatteryVoltage = 2;
				uint16_t batteryVoltage = SensorsBatteryvoltageGet();
				if (batteryVoltage <= 2800) {
					DeepDischargePrevention();
				}
			}
			checkBatteryVoltage--;
			SensorsOff();
			AdPowerdown();
		}
		checkInputVoltage--;
		//wakeup by alarm
		if (alarm) {
			if (checkAlarm == 0) { //1s passed
				alarm--;
				if (alarm == 0) {
					wakeupReason = 1;
					break; //wakeup
				}
				checkAlarm = 10;
			}
			checkAlarm--;
		}
		//wakeup by keypress, minimum 500ms, without keypress and then 500ms with keypress
		if ((powerByKeyState < 5) && (KeyPressedLeft() == 0) && (KeyPressedRight() == 0)) {
			powerByKeyState++;
		} else if ((powerByKeyState >= 5) && (powerByKeyState < 10)) {
			if ((KeyPressedLeft()) && (KeyPressedRight())) {
				powerByKeyState++;
			} else {
				powerByKeyState = 5;
			}
		} else if (powerByKeyState == 10) {
			LedOn();
			if ((KeyPressedLeft() == 0) && (KeyPressedRight() == 0)) {
				wakeupReason = 1;
				break;
			}
		}
		WatchdogReset();
		while (TimerHasOverflownIsr() == false) {
			WaitForInterrupt();
		}
	}
	LedOn();
	PinsPowerup();
	TimerFast();
	SensorsOn();
	ArmReset();
	waitms(1);
	ArmBatteryOn();
	waitms(10);
	ArmRun(); //we still have the pin set to start the usermode application
	return wakeupReason;
}

//value in [10ms]
#define KEY_PRESS_TIME_DEFAULT 100

int main(void) {
	HardwareInit(); //this sets the ARM to the reset state
	LedOn();
	TimerInit(true);
	waitms(50);
	ArmRun();
	waitms(950);
	LedOff();
	//otherwise the boot pin may not be set to high if no external
	//Vcc is applied (battery):
	ArmBatteryOn();
	SensorsOn();
	SpiInit();
	SpiDataSet(CMD_VERSION, 0x0507); //05 for the program (folder name), 07 for the version
	uint16_t pressedLeft = 0, pressedRight = 0; //Time the left or right button is hold down [10ms]
	uint8_t resetHold = 0; //count down until the reset of the ARM CPU is released [10ms]
	uint8_t armNormal = 1; //startup mode of the ARM cpu 0: DFU bootloader, 1: normal program start
	uint8_t ledFlashCycle = 0; //controls the speed of the LED flashing, counts up. [10ms]
	uint8_t ledFlashRemaining = 0; //if non 0, the LED is flashing
	uint8_t ledFlashOnSpiCommand = 1; //if 1, each SPI command is confirmed by a LED flash
	uint8_t adcCycleFast = 0; //cycle for measuring the analog inputs and calculating the battery charger logic
	uint8_t adcCycleSlow = 0; //cycle for measuring the analog inputs and calculating the battery charger logic
	uint8_t reinitSpiDelay = 0; //if reached 0, the SPI interface is reset
	uint16_t watchdogHighest = 0; //reload value of the ARM cpu watchdog, 0 = disabled [1ms]
	uint16_t watchdogCurrent = 0; //count down value of the ARM CPU watchdog. On a 0, a reset is issured. [1ms]
	uint16_t inU = 0; //measured input voltage [mV]
	uint16_t battU = 0; //measured battery voltage [mV]
	uint16_t battUmin = 0xFFFF; //minimum measured battery voltage [mV]
	uint16_t battI = 0; //measured battery current [mA]
	int16_t battTemp = 0; //measured battery temperature [0.1°C]
	uint16_t inMax = 70; //maximum allowed charging current [mA]
	uint8_t requestFullCharge = 0; //If set to 1, a full charge is requested
	uint8_t battPwm = 0; //last output PWM value controlling the battery charging current
	uint16_t cycle = 0; //cycle for statistics. Resets every minute
	uint32_t opRunning = 0; //counts the minutes since last power down
	uint16_t minutesSinceSave = 0; //If reached 1day, statistics are saved int eeprom
	uint8_t requestPowerDown = 0; //if 1 the ARM device will be powered down if currently running on battery
	uint16_t batteryWakeupTime = 0; //power up time in [s] when running on battery
	uint8_t batteryMode = 0; //if on battery, 0 = power down, 1 = continue to operate
	uint8_t onUsbPower = 1; //current source for the power. 0 = battery, 1 = USB
	uint8_t delayedPowerDown = 0; //if this counter reached zero when running on battery, there will be a request to power down
	uint8_t timeLoadLast = 0; //timestamp the last time the Load was updated [10ms]
	uint32_t ticksIdle = 0; //accumulated ticks of noting to do since timeLoadLast was updated
	uint8_t percentIdlePrevious = 0; //previous value of being idle in [%]
	uint16_t keyPressTime = KEY_PRESS_TIME_DEFAULT; //duration of the left or right key being pressed in [10ms]

	chargerState_t CS;
	persistent_t settings;
	SettingsLoad(&settings);
	SpiDataSet(CMD_OPTIME, settings.opTotal / (60UL * 24UL));
	SpiDataSet(CMD_LED_READ, ledFlashOnSpiCommand);
	SpiDataSet(CMD_BAT_CURRENT_MAX_READ, inMax);
	ChargerInit(&CS, settings.chargerError, settings.chargingCycles, settings.prechargingCycles, settings.chargingSumAllTimes);
	uint8_t timestampChargeprocessLast = TimerGetValue(); //time in [10ms]
	for (;;) { //Main loop, we run every 10ms
		if (KeyPressedLeft()) {
			if (pressedLeft < 0xFFFF) {
				pressedLeft++;
			}
			if (pressedLeft == keyPressTime) { //1s press (if default value)
				if (KeyPressedRight() == 0) {
					resetHold = 20; //200ms reset signal
					if (armNormal) {
						ArmUserprog(); //could have been overwritten by coprocCommand
					} else {
						ArmBootload();
					}
					reinitSpiDelay = 200;
					SpiDisable();
					ArmReset();
				} else {
					requestPowerDown = 1;
				}
			}
			if (pressedLeft >= keyPressTime) {
				ledFlashRemaining = 1;
			}
		} else {
			pressedLeft = 0;
			if (resetHold) {
				resetHold--;
				if (resetHold == 0) {
					keyPressTime = KEY_PRESS_TIME_DEFAULT;
					ArmRun();
					LedOff();
				}
			}
		}
		if ((KeyPressedRight()) && (KeyPressedLeft() == 0)) {
			if (pressedRight < 0xFFFF) {
				pressedRight++;
			}
			if (pressedRight == keyPressTime) { //1s press (if default value)
				armNormal = 1 - armNormal;
				if (armNormal) {
					ArmUserprog();
					ledFlashRemaining = 2; //1x flash
				} else {
					ArmBootload();
					ledFlashRemaining = 4; //2x flash
				}
			}
		} else {
			pressedRight = 0;
		}
		if (reinitSpiDelay) {
			reinitSpiDelay--;
			if (reinitSpiDelay == 0) {
				SpiInit();
			}
		}
		if ((reinitSpiDelay == 0) && (SpiProcess())) {
			uint16_t parameter;
			uint8_t command = SpiCommandGet(&parameter);
			if (ledFlashOnSpiCommand) {
				ledFlashRemaining = 2;
			}
			if (command == CMD_REBOOT) {
				bool rebootValid = false;
				if (parameter == 0xA600) {
					rebootValid = true;
				}
				if (parameter == 0xA601) {
					ArmUserprog();
					rebootValid = true;
				}
				if (parameter == 0xA602) {
					ArmBootload();
					rebootValid = true;
				}
				if (rebootValid) {
					ArmReset();
					resetHold = 20; //to be released in 200ms
				}
			} else if (command == CMD_LED) {
				ledFlashOnSpiCommand = parameter & 1;
				SpiDataSet(CMD_LED_READ, ledFlashOnSpiCommand);
			} else if (command == CMD_WATCHDOG_CTRL) {
				watchdogHighest = parameter;
				watchdogCurrent = watchdogHighest;
				SpiDataSet(CMD_WATCHDOG_CTRL_READ, watchdogHighest);
			} else if ((command == CMD_WATCHDOG_RESET) && (parameter == 0x42)) {
				watchdogCurrent = watchdogHighest;
			} else if ((command == CMD_BAT_CURRENT_MAX) && (parameter <= 200)) {
				inMax = parameter;
				SpiDataSet(CMD_BAT_CURRENT_MAX_READ, inMax);
			} else if ((command == CMD_BAT_FORCE_CHARGE) && (parameter == 0)) {
				requestFullCharge = 1;
			} else if ((command == CMD_BAT_NEW) && (parameter == 0x1291)) {
				settings.chargerError = 0;
				ChargerInit(&CS, settings.chargerError, settings.chargingCycles, settings.prechargingCycles, settings.chargingSumAllTimes);
				PwmBatterySet(0);
				SettingsSave(&settings);
			} else if ((command == CMD_BAT_STAT_RESET) && (parameter == 0x3344)) {
				settings.chargingCycles = 0;
				settings.prechargingCycles = 0;
				settings.chargingSumAllTimes = 0;
				ChargerInit(&CS, settings.chargerError, settings.chargingCycles, settings.prechargingCycles, settings.chargingSumAllTimes);
				PwmBatterySet(0);
				SettingsSave(&settings);
			} else if ((command == CMD_POWERMODE) && (parameter < 2)) {
				batteryMode = parameter;
				SpiDataSet(CMD_POWERMODE_READ, batteryMode);
			} else if (command == CMD_ALARM) {
				batteryWakeupTime = parameter; // 0 == never
				SpiDataSet(CMD_ALARM_READ, batteryWakeupTime);
			} else if (command == CMD_POWERDOWN) {
				requestPowerDown = 1;
			} else if ((command == CMD_KEYPRESSTIME) && (parameter >= 1000) && (parameter <= 60000)) {
				keyPressTime = parameter / 10; //[ms] -> [10ms]
			}
		}
		if (watchdogCurrent) {
			if (watchdogCurrent > 10) {
				watchdogCurrent -= 10;
			} else {
				watchdogCurrent = 0;
				ArmReset();
				resetHold = 20; //to be released in 200ms
			}
		}
		//update every 100ms
		if (ledFlashRemaining) {
			if (ledFlashCycle == 0) {
				uint8_t light = (ledFlashRemaining & 1) ^ (battPwm > 0);
				if (light) {
					LedOn();
				} else {
					LedOff();
				}
			}
			ledFlashCycle++;
			if (ledFlashCycle == 10) {
				ledFlashRemaining--;
				ledFlashCycle = 0;
			}
		} else if (battPwm) {
			LedOn();
		} else {
			LedOff();
		}
		//resets every 100ms, but each cycle does something different
		adcCycleFast++;

		if (adcCycleFast == 1) {
			battI = SensorsBatterycurrentGet(); //always measure the current before the input voltage
			SpiDataSet(CMD_BAT_CURRENT, battI);
		}
		if (adcCycleFast == 3) {
			battU = SensorsBatteryvoltageGet();
			SpiDataSet(CMD_BAT_VOLTAGE, battU);
			if (battU < battUmin) {
				battUmin = battU;
				SpiDataSet(CMD_BAT_MIN_VOLTAGE, battUmin);
			}
		}
		if (adcCycleFast == 5) {
			inU = SensorsInputvoltageGet();
			SpiDataSet(CMD_VCC, inU);
		}
		if (adcCycleFast == 7) {
			uint8_t timestamp = TimerGetValue();
			uint8_t delta = timestamp - timestampChargeprocessLast;
			uint16_t msPassed = (uint16_t)delta * 10; //timer is running every 10ms
			if (msPassed >= 50) { //in the case of a time catchup or first start, calling could be faster than 50ms
				battPwm = ChargerCycle(&CS, battU, inU, battI, battTemp, inMax, msPassed, requestFullCharge);
				requestFullCharge = 0;
				PwmBatterySet(battPwm);
			}
			timestampChargeprocessLast = timestamp;
		}
		if (adcCycleFast == 10) { //updates every 100ms
			adcCycleFast = 0;
			adcCycleSlow++;
			if (adcCycleSlow == 1) { //call every 500ms
				//calculation takes 24ms with F_CPU=107000
				battTemp = SensorsBatterytemperatureGet();
				SpiDataSet(CMD_BAT_TEMPERATURE, battTemp);
			}
			if (adcCycleSlow == 2) {
				//needs 13ms with F_CPU=107000
				uint16_t cpuTemperature = SensorsChiptemperatureGet();
				SpiDataSet(CMD_CPU_TEMPERATURE, cpuTemperature);
			}
			if (adcCycleSlow == 3) {
				SpiDataSet(CMD_BAT_CHARGE_STATE, ChargerGetState(&CS));
				SpiDataSet(CMD_BAT_CHARGE_ERR, ChargerGetError(&CS));
				SpiDataSet(CMD_BAT_CHARGED, ChargerGetCharged(&CS) / (60ULL*60ULL)); //mAs -> mAh
				settings.chargingSumAllTimes = ChargerGetChargedTotal(&CS);
				SpiDataSet(CMD_BAT_CHARGED_TOT, settings.chargingSumAllTimes / (1000ULL * 60ULL * 60ULL * 1000ULL)); //mAms ->Ah
				settings.chargingCycles = ChargerGetCycles(&CS);
				SpiDataSet(CMD_BAT_CHARGE_CYC, settings.chargingCycles);
				settings.prechargingCycles = ChargerGetPreCycles(&CS);
				SpiDataSet(CMD_BAT_PRECHARGE_CYC, settings.prechargingCycles);
				SpiDataSet(CMD_BAT_PWM, battPwm);
				uint32_t timeS = ChargerGetTime(&CS) / 1000;
				SpiDataSet(CMD_BAT_TIME, timeS);
				SpiDataSet(CMD_BAT_CHARGE_NOCURR_VOLT, ChargerGetNoCurrentVoltage(&CS));
			}
			if (adcCycleSlow == 5) {
				adcCycleSlow = 0;
			}
		}
		//check if we should power down. Triggers when >= 4500mV and then <= 4000mV
		if (inU >= 4500) {
			onUsbPower = 1;
		}
		if (inU <= 4000) {
			if ((onUsbPower) && (batteryMode == 0)) {
				/*Sometimes power just goes off for a short moment, in this case
				  the battery should just act as UPS for 500ms */
				delayedPowerDown = 50;
			}
			onUsbPower = 0;
			if (delayedPowerDown) {
				delayedPowerDown--;
				if (delayedPowerDown == 0) {
					requestPowerDown = 1;
				}
			}
		}
		if ((onUsbPower == 0) && (battU <= 3100) && (battU)) { //prevent full discharge. We may go down to 3V
			requestPowerDown = 1;
		}
		if (requestPowerDown) {
			requestPowerDown = 0;
			if (onUsbPower == 0) {
				keyPressTime = KEY_PRESS_TIME_DEFAULT;
				uint8_t wakeupReason = PowerDownLoop(batteryWakeupTime);
				timestampChargeprocessLast = TimerGetValue();
				reinitSpiDelay = 100;
				if (wakeupReason == 2) {
					/* Otherwise the device would stay on, when the USB power is only
					   applied for a very short time, enough for only one measurement.
					   This happens at least on one PC, when it is shut down.
					*/
					onUsbPower = 1;
				}
			}
		}
		//update CPU load (nees ~400byte flash, so remove, should flash size be a problem)
		{
			uint8_t time = TimerGetValue();
			uint8_t delta = time - timeLoadLast;
			if (delta >= 100) {
				/* A delta of 100 would be best. But if not we need to scale down. So:
				   scaledIdle = ticksIdle * 100 / delta;
				   To get percent of ticks idle:
				   percent = scaledIdle * 100 / ticksPerSecond
				   This merges to:
				   percent = (ticksIdle * 100000) / (delta * ticksPerSecond)
				*/
				uint32_t percentIdle = ((uint32_t)ticksIdle * 10000UL) / ((uint32_t)delta * TimerGetTicksPerSecond());
				SpiDataSet(CMD_CPU_LOAD, 100 - (uint8_t)percentIdlePrevious); // convert from idle to load
				percentIdlePrevious = percentIdle; //have 1s delay to poll this value without the polling changing this value
				timeLoadLast = time;
				ticksIdle = 0;
			}
		}
		//update statistics and save to eeprom
		cycle++;
		if (cycle == (100 * 60)) { //1m passed
			cycle = 0;
			opRunning++;
			SpiDataSet(CMD_UPTIME, opRunning / 60UL);
			settings.opTotal++;
			SpiDataSet(CMD_OPTIME, settings.opTotal / (60UL * 24UL));
			minutesSinceSave++;
			if (minutesSinceSave == (60 * 24)) { //1 day passed
				minutesSinceSave = 0;
				SettingsSave(&settings);
			}
		}
		WatchdogReset();
		uint16_t ticksToInterrupt = TimerGetTicksLeft();
		if (TimerHasOverflownIsr() == false) {
			ticksIdle += ticksToInterrupt;
			while (TimerHasOverflownIsr() == false) {
				WaitForInterrupt();
			}
		}
	}
}

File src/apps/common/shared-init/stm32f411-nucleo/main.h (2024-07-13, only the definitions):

#define KeyLeft_Pin GPIO_PIN_13
#define KeyLeft_GPIO_Port GPIOC
#define KeyUp_Pin GPIO_PIN_8
#define KeyUp_GPIO_Port GPIOA
#define KeyDown_Pin GPIO_PIN_1
#define KeyDown_GPIO_Port GPIOC
#define KeyRight_Pin GPIO_PIN_0
#define KeyRight_GPIO_Port GPIOC
#define Led1Green_Pin GPIO_PIN_5
#define Led1Green_GPIO_Port GPIOA
#define LcdCs_Pin GPIO_PIN_10
#define LcdCs_GPIO_Port GPIOB
#define LcdReset_Pin GPIO_PIN_4
#define LcdReset_GPIO_Port GPIOB
#define LcdA0_Pin GPIO_PIN_5
#define LcdA0_GPIO_Port GPIOB
#define LcdBacklight_Pin GPIO_PIN_5
#define LcdBacklight_GPIO_Port GPIOA
#define PerSpiSck_Pin GPIO_PIN_0
#define PerSpiSck_GPIO_Port GPIOB
#define PerSpiMiso_Pin GPIO_PIN_12
#define PerSpiMiso_GPIO_Port GPIOA
#define PerSpiMosi_Pin GPIO_PIN_10
#define PerSpiMosi_GPIO_Port GPIOA
#define TMS_Pin GPIO_PIN_13
#define TMS_GPIO_Port GPIOA
#define TCK_Pin GPIO_PIN_14
#define TCK_GPIO_Port GPIOA
#define SWO_Pin GPIO_PIN_3
#define SWO_GPIO_Port GPIOB
#define Rs232Tx_Pin GPIO_PIN_2
#define USART_TX_GPIO_Port GPIOA
#define Rs232Rx_Pin GPIO_PIN_3
#define USART_RX_GPIO_Port GPIOA

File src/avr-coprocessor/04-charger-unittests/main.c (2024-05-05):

/*UniversalboxARM - AVR coprocessor
  (c) 2022 by Malte Marwedel
  www.marwedels.de/malte

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
  Features:
  This project just runs the unit tests for the charger logic on the AVR.
  As sizeof(int) is just 16bit, results may be different than when run on a PC.
  So running on the target AVR verifies the tests already done on the PC.

  Connect a serial cable to PORTA pin 1 with 1200 baud to see some data.

  Pin connection:
  PINA.0 = Input, AVR DI
  PINA.1 = Output, AVR DO and boot pin state (high state = bootloader)
  PINA.2 = Input, AVR SCK
  PINA.3 = Input, AREF
  PINA.4 = Input, Battery voltage measurement
  PINA.5 = Input, Vcc measurement
  PINA.6 = Input, Voltage drop for charge current measurement
  PINA.7 = Output, pull high to set ARM into reset state.
  PINB.0 = Output, pull down to power the ARM by battery (PCB with fix). (MOSI for ISP)
  PINB.1 = Output, User LED (MISO for ISP)
  PINB.2 = Input with pullup, right key (SCK for ISP)
  PINB.3 = Output, PWM for battery charging (OC1B). Set to 0V to disable charging
  PINB.4 = Output, Power save option, set high to enable temperature and battery
                   voltage measurement, low disconnects the voltage dividers
  PINB.5 = Input, Battery temperature measurement (PCB with fix)
  PINB.6 = Input with pullup, left key (allows wakeup from power down by Int0)
           If workaround for teperature sensor is applied: Input without pullup,
           temperature sensor can be read as long as key is not pressed
  PINB.7 = reset pin

  Set F_CPU to 8MHz and the fuses to use the internal 8MHz oscillator.

  WARNING: While an ISP programmer is connected, the right button may not be
           pressed, as this would short circuit SCK of the programmer to ground.

  Note: Strings have been moved to the eeprom - simply because the flash is full.
  The resulting code could be shorter - but the old gcc 5 provided by Debian 11
  ignores some optimization, like removing the unused interrupt vector table
  (-mno-interrupts) or unused functions (-ffunction-sections).

History:
 v0.10 2022-06-26
 v0.9 2022-06-24
 v0.1 2022-05-31

*/

#include <stdlib.h>
#include <stdint.h>
#include <string.h>
#include <stdbool.h>

#include <avr/eeprom.h>

#include "hardware.h"
#include "timing.h"
#include "softtx.h"
#include "femtoVsnprintf.h"
#include "chargerStatemachine.h"
#include "utility.h"
#include "counter.h"

#define TASSH(X, Y) if (!(X)) {return Y;}

typedef struct {
	uint16_t battU;
	uint16_t inU;
	uint16_t battI;
	int16_t battTemp;
	uint16_t inImax;
	uint8_t requestCharge;
	uint16_t pwmMax;
	uint16_t pwmMin;
	uint16_t pwmOut;
	uint16_t maxTicks;
} input_t;

uint32_t g_maxTicks;

static void myprintf(const char *format, ...) {
	va_list args;
	va_start(args, format);
	char formatRam[64];
	formatRam[sizeof(formatRam) - 1] = '\0';
	uint8_t i = 0;
	do {
		formatRam[i] = eeprom_read_byte((const uint8_t*)format);
		format++;
		i++;
	} while ((i < (sizeof(formatRam) - 1)) && (formatRam[i - 1]));
	char buffer[96];
	femtoVsnprintf(buffer, sizeof(buffer), formatRam, args);
	va_end(args);
	print(buffer);
}

const char EEMEM strPwm[] = "Pwm out of bounds, is %u\r\n";

static bool StepForward(chargerState_t * pCs, uint32_t miliseconds, input_t * data) {
	CounterStart();
	data->pwmOut = ChargerCycle(pCs, data->battU, data->inU, data->battI, data->battTemp, data->inImax, miliseconds, data->requestCharge);
	uint32_t ticks = CounterGet();
	data->maxTicks = MAX(data->maxTicks, ticks);
	if ((data->pwmOut > data->pwmMax) || (data->pwmOut < data->pwmMin)) {
		myprintf(strPwm, (unsigned int)data->pwmOut);
		return false;
	}
	return true;
}

static bool TimeForward(chargerState_t * pCs, uint32_t miliseconds, input_t * data) {
	bool success = true;
	do {
		uint32_t cyc = miliseconds;
		if (miliseconds > 150) {
			cyc = 100;
		}
		miliseconds -= cyc;
		success &= StepForward(pCs, cyc, data);
	} while (miliseconds);
	return success;
}

static bool TimeForwardS(chargerState_t * pCs, uint32_t seconds, input_t * data) {
	return TimeForward(pCs, seconds * 1000UL, data);
}

const char EEMEM strError[] = "Error should %u, is %u\r\n";

static bool CheckErrorExpected(chargerState_t * pCs, uint8_t should) {
	uint8_t errorState = ChargerGetError(pCs);
	if (errorState == should) {
		return true;
	}
	myprintf(strError, (unsigned int)should, (unsigned int)errorState);
	return false;
}

static bool CheckStateExpected(chargerState_t * pCs, uint8_t should) {
	if (ChargerGetState(pCs) == should) {
		return true;
	}
	return false;
}

const char EEMEM strFailed[] = "Test %u failed, with code %u\r\n";

static void PrintFailed(uint16_t testnumber, uint8_t errorCode) {
	myprintf(strFailed, (unsigned int)testnumber, (unsigned int)errorCode);
}

const char EEMEM strTickAnalzye[] = "Max ticks: %u\r\n";

static void TicksAnalyze(input_t * data) {
	myprintf(strTickAnalzye, (unsigned int)data->maxTicks);
	g_maxTicks = MAX(g_maxTicks, data->maxTicks);
}

//Under this conditions, the charging should start
static void CommonStartCondition(input_t * data) {
	data->battU = 3100;
	data->inU = 4700;
	data->battI = 0;
	data->battTemp = 250;
	data->inImax = 100;
	data->requestCharge = 0;
	data->pwmMin = CHARGER_PWM_MAX / 2;
	data->pwmMax = CHARGER_PWM_MAX;
	data->maxTicks = 0;
}

static void ChargerInitCommon(chargerState_t * pCs) {
	ChargerInit(pCs, 0, 0, 0, 0);
}

//just do nothing, because the battery is full
static uint8_t test1(void) {
	chargerState_t cs;
	ChargerInitCommon(&cs);
	input_t data;
	CommonStartCondition(&data);
	data.battU = 3350;
	data.pwmMin = 0;
	data.pwmMax = 0;
	TASSH(TimeForwardS(&cs, 100, &data), 1);
	TASSH(CheckErrorExpected(&cs, 0), 2);
	TASSH(CheckStateExpected(&cs, 0), 3);
	TicksAnalyze(&data);
	return 0;
}

//just do nothing, because the charging current is limited to 0
static uint8_t test2(void) {
	chargerState_t cs;
	ChargerInitCommon(&cs);
	input_t data;
	CommonStartCondition(&data);
	data.inImax = 0;
	data.pwmMin = 0;
	data.pwmMax = 0;
	TASSH(TimeForwardS(&cs, 100, &data), 1);
	TASSH(CheckErrorExpected(&cs, 0), 2);
	TASSH(CheckStateExpected(&cs, 0), 3);
	TicksAnalyze(&data);
	return 0;
}

//reject, if initialized in error state
static uint8_t test3(void) {
	chargerState_t cs;
	ChargerInit(&cs, 1, 0, 0, 0);
	input_t data;
	CommonStartCondition(&data);
	data.pwmMin = 0;
	data.pwmMax = 0;
	TASSH(TimeForwardS(&cs, 1, &data), 1);
	TASSH(CheckErrorExpected(&cs, 1), 2);
	TASSH(CheckStateExpected(&cs, 0), 3);
	TicksAnalyze(&data);
	return 0;
}
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

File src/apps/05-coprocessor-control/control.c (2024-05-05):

/* Coprocessor-control
(c) 2022 by Malte Marwedel

SPDX-License-Identifier: GPL-3.0-or-later
*/

#include <stdint.h>
#include <stdbool.h>
#include <stdio.h>
#include <string.h>
#include <stddef.h>
#include <ctype.h>
#include <stdlib.h>
#include <time.h>

#include "control.h"

#include "boxlib/keys.h"
#include "boxlib/leds.h"
#include "boxlib/rs232debug.h"
#include "boxlib/lcd.h"
#include "boxlib/flash.h"
#include "boxlib/peripheral.h"
#include "boxlib/coproc.h"
#include "boxlib/mcu.h"
#include "boxlib/readLine.h"

#include "main.h"

#include "utility.h"
#include "femtoVsnprintf.h"

#include "gui.h"
#include "filesystem.h"
#include "screenshot.h"

uint32_t g_cycleTick;

void ControlHelp(void) {
	printf("h: Print help\r\n");
	printf("r: Reset\r\n");
	printf("p: Read out all data from the coprocessor\r\n");
	printf("n: New battery\r\n");
	printf("x: Reset battery stats\r\n");
	printf("f: Force full charge\r\n");
	printf("c: Set maximum current\r\n");
	printf("o: Power down - off\r\n");
	printf("t: Set alarm\r\n");
	printf("m: Set mode on disconnect\r\n");
	printf("g: Freeze / unfreeze GUI\r\n");
	printf("e: Screenshot\r\n");
	printf("w-a-s-d: Send key code to GUI\r\n");
}

void AppInit(void) {
	LedsInit();
	Led1Yellow();
	PeripheralPowerOff();
	HAL_Delay(100);
	PeripheralPowerOn();
	Rs232Init();
	printf("\r\nCoprocessor control %s\r\n", APPVERSION);
	printf("h: Print help\r\n");
	Rs232Flush();
	uint8_t error = McuClockToHsiPll(32000000, RCC_HCLK_DIV2);
	if (error) {
		printf("Error, failed to increase CPU clock - %u\r\n", error);
	}
	KeysInit();
	CoprocInit();
	PeripheralInit();
	FlashEnable(4); //4MHz
	FilesystemMount();
	GuiInit();
	Led1Off();
	g_cycleTick = HAL_GetTick();
}

void ExecReset(void) {
	printf("Reset selected\r\n");
	Rs232Flush();
	NVIC_SystemReset();
}

void TemperatureToString(char * output, size_t len, int16_t temperature) {
	char sign[2] = {0};
	if (temperature != INT16_MIN) {
		if (temperature < 0) {
			sign[0] = '-';
			temperature *= -1;
		}
		unsigned int degree = temperature / 10;
		unsigned int degree10th = temperature % 10;
		femtoSnprintf(output, len, "%s%u.%u°C", sign, degree, degree10th);
	} else {
		femtoSnprintf(output, len, "n/a");
	}
}

const char * g_chargerState[STATES_MAX] = {
"Battery full, not charging",
"Battery charging",
"Battery temperature out of bounds",
"No battery / battery defective",
"Battery voltage overflow. Battery defective",
"Input voltage too low for charge",
"Input voltage too high for charge",
"Battey precharging because of very low voltage",
"Failed to fully charge",
"Software failure",
"Charger defective"
};


const char * g_chargerError[ERRORS_MAX] = {
"No error",
"Battery voltage too high - defective",
"Battery voltage too low - defective, or started without a battery inserted",
"Failed to fully charge - charger or battery defective",
"Too high current - charger or battery defective",
"Too low current - charger or battery defective",
};
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

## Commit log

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2021-12-03 Update schematic, replace resistor by diode Also make the schematic more easy to read
    [UniversalboxArm1-0.kicad_pcb, UniversalboxArm1-0.sch]
2021-12-18 Update schematic to version 1 revision 0.5 Reflecting issues found while getting pcb to work
    [UniversalboxArm1-0.kicad_pcb, UniversalboxArm1-0.sch, bom-v1-0.ods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]
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2021-12-20 AVR: Update minimal application to PCB fixes
    [hardware.h, main.c]
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2021-12-29 Schematic: Rearrange text to avoid overlapping with wires
    [UniversalboxArm1-0.sch]
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2022-01-02 STM32: Add testcode for using the LCD Schematic: Document the missing pullup on the reset line of the LCD BOM: Add missing capacitor
    [UniversalboxArm1-0.sch, bom-v1-0.ods]
2022-01-17 Schematic: Revision 0.8 Workaround for issues with the crystals Reduce the value of two resistors
    [UniversalboxArm1-0.kicad_pcb, UniversalboxArm1-0.sch, bom-v1-0.ods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]
2022-01-19 Add coprocessor firmware with SPI interface. Add ARM firmware to test the SPI interface and test the LSE and HSE oscillators Also reorganize source to make shared files between firmwares easier to us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
    [configuration.h]
2022-01-31 STM32: Add test for ESP and ADC. Add workaround for SPI input from flash - test which prescalers allow a communication. Run on HSI instead of MSI by default. Properly calculate the timing when switch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
    [main.c]
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2022-02-19 AVR: Make sure the ARM always boots into normal program mode and not the bootloader when powering on The pins are properly set by the AVR ~0.39ms after power is applied. And then ARM is kept in reset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
    [hardware.c, hardware.h, main.c]
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2022-02-20 Schematic: Revision 0.9 Add worarounds for electric issues when the internal bootloader is active - bug 10. Document bug 11 - wrong signal names on PCB
    [UniversalboxArm1-0.kicad_pcb, UniversalboxArm1-0.sch, bom-v1-0.ods]
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2022-02-27 STM32: Move ili9341 init sequence from ST to another name. The sequence is just not working. The file is kept as reference. The commands in the header will be used for an own implementation.
2022-02-27 STM32: Add workig code for ILI9341 LCD. The code from ST was able to show a grey image and data could be read back from the status registers. But no correct image was visible on the LCD. The other in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
2022-03-17 STM32: Add early version of loader project. Implements DFU. GUI still missing.
    [main.c, main.h]
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2022-04-13 Boxlib, Algorithm: Make framebuffer work with 128x128 LCD
    LcdWriteRect now works for the ST7735 controller.
    Colors fixed - high and low bytes were swapped.
    Now uses reset pin before LCD init.
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2022-04-25 STM32: Fix build dependencies for 02-test-everything-hal project
    Need to create build folder first.
2022-04-25 Common: Fix color ordering of 128x128 ST7735 LCD
    Red and blue colors were switched in the output.
2022-04-25 Common: Fix colors in boxlib and last line not drawn
    Colors were mixed up by high and low byte exchanged,
    which was partially concealed by the red and green color
    switched within the LCD controller.
    Morever only 127 lines of a 128x128 or 128x160 LCD were drawn.
    The LCD testpattern now contains a fading color bar to check proper
    bit positioning.
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2022-04-25 STM32: Implement GUI for the 03-loader project
    Also implement autostart option.
    The GUI is more or less complete - only the 128x128 LCD has been tested.
    Known Bugs:
    1. Saving transferred programs does not work if saving was not already
    requested during transfer.
    2. The 320x240 LCD likely does not work - because it has not been tested with
    the framebuffer output.
    3. The screen is not properly updated if a second progam is transferred.
    4. Date is not set to the files - could be guessed from the tar archive even
    without a clock.
    5. If the loader is running from RAM, the memory presented in the DFU
    description is too large.
    [main.c]
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2022-05-07 STM32: Loader now feature complete
    320x240 LCD tested
    160x128 LCD known to be untested
    Memory for stack reserved increased to 4KiB
    Filesystem now has a label
    Files created now have a timestamp, tar files uses the timestamp from the application file.
    If running from RAM, the loader provides up to 64KiB instead for 32KiB for DFU uploads.
    The DFU descriptor reports the correct maximum code size.
    The loader should not exceed 64KiB of codesize to work on future STM32F730.
    The screen is properly updated on a second program upload.
    Saving a program works as intended.
    The pc simulation now supports multiple upload options.
    Improvements for next versions:
    Faster LCD drawing.
    Reduce code size to have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
    [main.c]
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2022-05-08 STM32: Fix background color level in Loader project
    When transferring another program while a GFX was shown, the color level
    was not reset to the correct value when switching to the application window.
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2022-05-08 Common: Speed improve drawing with ILI9341 controller
    As usually drawing is done line by line and the width stays the same,
    writing the unchanged borders can be skipped. This improves the total
    frame drawing speed by about 5% (assuming 16MHz CPU, 8MHz SPI frequency)
    to 445ms per frame.
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2022-05-19 STM32: Loader: Add message in error case of HAL
    Document DFU performance compared to the USB buffer size.
    [main.c, main.h]
2022-05-19 STM32: Loader: Format the external flash from serial terminal
    Was only possible from the LCD, which is difficult to select if the
    filesystem is corrupted.
    Also prevent automatic fomatting if the flash signature can not be read.
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2022-05-23 Algorithm: Fix bufferoverflow in framebufferLowmem
    As this was only a read access, no data corruption had occurred.
    Found by AddressSanitize
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2022-06-06 AVR: Fix timer frequency setup
    Was not working with F_CPU values above 1MHz
    [hardware.h]
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2022-06-24 AVR: Add check to charger statemachine if current is too high.
    Adds a testcase too. Flash is now filled to the last byte.
    [chargerStatemachine.c, main.c]
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2022-08-20 AVR: 05-spi-with-charger: Improvements, bugfix AVR: Common: Add functions to wait for timer in the idle mode
    Common:
    The idle mode saves some power consumption.
    Also allows wake up by the left key from power down mode.
    05-spi-with-charger:
    Bugfix: Reading the temperature of the battery was an invalid value.
    Improvement: Debouncing the keys when powering down, also wait 500ms before power up.
    Reduce consumption in ARM off mode from 0.55mA to 0.50mA.
    Known bug: 0.5mA in ARM power off mode is still too much for a long battery life.
    [configuration.h]
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2022-08-21 AVR: 05-spi-with-charger: Improve power consumption, fix wakeup from deep power down
    Disabling the AVR hardware as far as possible reduces the power consumption of the
    AVR from ~200µA to ~90µA. Giving a total consumption of ~380µA when in ARM power off
    mode. Additional 285µA could be saved with a hardware fix.
    Bugfix: Wakeup from deep discharge prevention by keypress did not work.
    [main.c]
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2022-08-27 Common: Unify code for filesystem Pc-simulator: Optimize shell input processing STM32: 03-loader: Fix out of scope variable usage in pc-simulation
    pc-simulator:
    Now start an extra thread for reading from the shell.
    Simulates backlight on and off commands.
    Allows program termination by control+c.
    Reset terminal parameters as long as the program is properly terminated.
    Known bug: If the simulation crashes, char echo is missing in the shell input afterwards.
    03-loader:
    Increase text length of program info from 16 to 32 chars on the GUI
    [main.c]
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2022-09-25 STM32: 05-coprocessor-control: Increase drawing speed, get more data from coprocessor
    Optimize drawing and increase CPU clock to 32MHz
    Readback state of the coprocessor to set values of the GUI properly
    Fix key usage of the RS232 interface.
    [control.c]
2022-09-26 AVR: 05-spi-with-charger: Implement SPI readout commands. Fix bug after powerup
    When powering up by battery, SPI commands could not be executed. Not disabling
    the input for the SPI data signal solved this issue.
    Change makefile fuse configuration to not erase the eeprom on firmware upload.
    Fix a potential division by zero in temperature calculation.
    Report INT16_MIN as temperature for the battery when running on battery power.
    Documentation: Note the temperature sensor of the battery can only be read when
    running on USB power.
    [configuration.h]
2022-09-28 STM32: Boxlib: Add key input with interrupts
    Allows key input for programs which can look for the input pins only
    sporadically and would miss user inputs otherwise.
    Note: This implementation only detects an input on release, the non interrupt
    variant already on press down.
    The new variant avoids conflicts with the input for the coprocessor,
    where a long press down of the left or right key changes some modes.
    The old variant could have some actions triggered in the STM32 program,
    the user does not want.
    For the polling input file, a dummy init function has been added to allow
    switching between the two implementations more easily.
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2022-10-01 STM32: 02-test-everything: Add option to manually control coprocessor SPI signals AVR: 06-chip-bug-didr0-test: Testproject to rule out an AVR bug
    Also fixes different version numbers in 02-test-everything.
    Also makes the hardware lib for the AVR more flexible for the choosen F_CPU frequency.
    [configuration.h]
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2022-10-02 AVR: Common: Speed improvement for ADC functions
    By using 2^n dividers, slow divisions are avoided.
    Now the following cpu cycles are needed (approximated):
    Read battery temperature: ~2648
    Read MCU temperature: ~1400
    Read UVcc: ~472
    Read UBat: ~288
    Read IBat: ~1520
    [hardware.c]
2022-10-02 AVR: Common: Fix divisor calculation for some desired F_CPU frequencies
    Some F_CPU values resulted in half of the intended CPU frequency.
    [hardware.h]
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2022-10-02 AVR: 05-spi-with-charger: Fix timing, add CPU load command
    The progam now skips waits for an interrupt, if the 10ms timing
    has been exceeded. This makes sure the delay is catched and
    the timing is fixed as long as the main loop can be processed
    within the time on average within 2.5s.
    In order to not exceed the timing, the temperature is now read only
    every 500ms instead of every 100ms. The data for the SPI
    interface is only updated every 500ms too.
    Together with the optimized ADC conversion, now the CPU is
    approximately 50-60% in use with a 107kHz clock when no SPI
    communication is in progress.
    Previously about 200kHz as F_CPU would have been needed to keep to
    10ms main loop timing.
    Adds a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
    [configuration.h]
2022-10-03 AVR: Fix makefiles, remove obsolete file
    [main.h]
2022-10-03 STM32: Common: Fix key input with interrupt
    The previous implementation sometimes got struck in an endless interrupt.
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2022-10-21 STM32: Directly initialize UARTs in boxlib, avoiding HAL
    This saves ~1.8KiB of code from each firmware and should
    make porting to other target CPUs more easily by having just
    to adjust the boxlib.
    [main.c]
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2022-10-25 STM32: 03-loader: Fix file timestamp calculation
    Written .tar files did not get the proper file date and time from the .tar.
2022-10-25 STM32: 06-usb-mass-storage: Fix linker scripts
    Should not use linker script for the loader.
    Only when loading to an address not used when the loader runs from RAM,
    the loader from RAM can load and run this project.
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2022-10-30 Boxlib: Use ISR for ESP data RX, add higher level ESP access functions
    The use of an ISR should allow the usage with multiple tasks without data loss.
    Add basic implementation of ESP access for simulation on a PC host.
    Also move ESP clock mux configuration to boxlib to avoid duplicated code.
    And move BytesFlip() to utility.c.
    [main.c]
2022-10-30 Schematic: Version 0.11, update parts, reroute LCD reset
    LCD reset is now connected to PC2, this allows I2C on PC0 and PC1 to be used.
    R34 has been reduced to 470Ohm.
    Q61 and Q62 are replaced by IRLML6344 to switch higher currents.
    R55 has been added. This should allow to access the flash with 4MHz instead of 250kHz.
    Measurements on R55 show the required low level of 1V is now reached within 250ns.
    [UniversalboxArm1-0.kicad_pcb, UniversalboxArm1-0.sch, bom-v1-0.ods]
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2022-11-05 STM32: 06-usb-mass-storage: Fix double buffer transmit, use DMA, add benchmark, increase SPI clock
    Using SPI with DMA together with the USB and double buffer transmit results in
    some transmit events not generating a callback. Then the behaviour was as if
    no double buffer is used.
    Measurements with a scope show the flash MISO data line reaches 0.3*Vcc
    after 76ns. 0.3*Vcc is the limit of the STM32 to detect a low level
    guranteed by design. 76ns results in a maximum frequency of 6.57MHz.
    So 6MHz is expected to be the fastest safe value which has some margin for
    error left.
2022-11-05 AVR: 05-spi-with-charger: Bugfix, sometimes the device stayed on, when USB power was removed
    This happened, when the USB power was only applied for a short moment.
    In this case the device woke up and then never assumed to be powered by USB, as the
    next measurement resulted already in a too low voltage.
    [main.c]
2022-11-13 Common: Algorithm: Fix femtoVsnprintf, improve tests
    Last checkin resulted in all %u to be printed as hex.
    The new tests should prevent such error in the future.
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2022-11-15 STM32: 07-ntp-clock: Write time from server to internal RTC, allow manual input
    Also add more error checking of returned timestamps.
    Wifi config now uses key "ap1" and "password1", to allow multiple access points.
    Debug information of the RTC can be printed.
    GUI, timezone support and setting the NTP server is missing.
2022-11-15 STM32: 03-loader: Serve watchdog, cleanup code, do not try to start programs at an invalid location
    Starting at an invalid location just fails to work and results in strange behaviour.
    The watchdog is set to 20s and is served every 10s, unless a user input blocks the main thread.
    This should make it easier to run programs with a watchdog enabled, who resets themself,
    before their watchdog expires.
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2022-11-16 STM32: Replace ReadSerialLine by function from boxlib
    [control.c]
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2022-11-21 STM32: 03-loader: Do not write on every start, fix bufferoverflow, show version number
    Bugfix: Setting the filesystem label on every start resulted in writing the flash.
    When the power was removed in this moment, the filesystem ended to be corrupt.
    Bugfix: The filename selectd by the user was not guranteed to be \0 terminated.
    Improvement: Before formatting, the loading of the filesystem is tried three times
    and the flash communication is checked to be working reliable.
    Improvement: The GUI now shows the version number of the loader.
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2022-11-24 STM32: 05-coprocessor-control: Bugfix, do not make multiple screnshots when holding down the keys
    Add screenshot to documentation.
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2022-12-02 STM32: Replace exception and systick handling by own code
    Unify code and print some diagnostic messages in the case of a
    NMI (invalid access, div by zero...).
    Extend systick ISR, to be optionally used together with FreeRTOS.
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2022-12-17 Common: Boxlib: Make LCD and flash access thread safe
    The flash read and write functions should be fully thread safe.
    The LCD function are only thread safe for sharing the same
    SPI master with the flash. The LCD functions itself should still
    only be called from one thread.
    Bugfix: BlashWriteBuffer1 did not set the clock divider.
2022-12-20 Algorithm: Fix color processing of framebufferColor
    Red and blue bits were internally assumed to be at the wrong position.
    As in and output were switched, this only had an effect if the number
    of bits used for red, green and blue were not equal.
2022-12-20 STM32: 07-ntp-clock: Make thread safe, continue GUI
    The previous version was not thread safe for using the LCD and
    flash. Also not for the filesystem.
    The GUI now supports entering wifi data, NTP server and colors.
    Framebuffer colors are now RGB 3-3-2 bits. This allows to use
    the menu graphics with maximum compression.
    Some config settings are still missing in the GUI.
    A large clock is missing too.
2022-12-28 Utilities: ppm2menuimage: Support up to 8 bit output colors, add large digits
    The exporter now supports output formats up to 8bit, instead of fixed 3bit.
    The digits 0-9 and colon in the size of 24x43 and 58x105 are added, they look
    like 7-segment LEDs.
    The digits are under public domain and can be used for any purpose.
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2023-04-01 Schematic: Fix power surge of ESP-01 module
    Add C121, reduce C120. Make C4 not recommend.
    Schematic vesion 0.12.
    [UniversalboxArm1-0.kicad_pcb, UniversalboxArm1-0.sch, bom-v1-0.ods]
2023-07-05 Common: Algorithm: Add menu_screen_size_get, fix menu_screen_size
    menu_screen_size_get has been added for easily getting the screen resolution.
    menu_screen_size had a wrong type as parameter, not fitting to the header.
    The headers of the different framebuffer implementations are unified.
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2023-07-09 Common: Algorithm: Fix crash in clock init after deinit
    If some other thread is waiting for the mutex, the mutext may not be re-created.
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2023-07-27 STM32: 09-gamebox: Restructure folders and makefiles, fix buffer overflows
    Version 1.03
    The folder structure now is similar to the other projects and object files
    of the different platforms do not write over each other anylonger.
    Also the pc-simulation now links again.
    Found by asan, two buffer overflows have been fixed.
    [main.c, main.h, timing.c]
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2023-07-27 STM32: 09-gamebox: Fix compiler warnings, fix bad build dependency
    Building the AVR version with -j only worked every second time, because
    the clean target ran at the same time.
    [main.c, timing.c]
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2023-07-29 Boxlib: Fix thread safeness of flash and LCD access
    The flash access missed using the lock when writing.
    The LCD already released the lock after the first command was send
    and before the pixel data were sent.
2023-07-29 STM32: 09-gamebox: Add port to ARM
    Implement input by joystick, cursor and serial debug port.
    Joystick calibration will be stored on the filesystem.
    Implement output on LCD.
    Highscore will be stored on the filesystem.
    The watchdog is served, if enabled.
    The demo shows graphic errors when using the tigometric functions,
    these are not present when compiling for the PC or AVR.
    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
    [gamebox.h, main.c]
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2023-11-28 Common: Pc-Simulation: Bugfix, programs were not working with GLUT 3.0
    Newer GLUT requires the callback to be set, and otherwise terminates the
    application with "No display callback registered for window".
    The newer GLUT version is delivered with Debian 12, so the upgrade from Debian 11
    made all pc based simulations of STM32 programs non working.
2023-12-29 Common: Algorithm: Fix programs not working with GCC 12
    The new compiler replaced the size optimized strlen implementation
    with a call to strlen, ending in an endless loop.
    This made all programs which compiled libcMinsize.c to be not working
    anylonger when switching from Debian 11 to Debian 12 (which delivers GCC 12).
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2024-01-01 STM32: 09-gamebox: Make all games work with keys, no need for a joystick
    There still needs to be an option to extend the time until the coprocessor
    does a reset. Until then, some games are difficult to play.
    [main.c, userinput.c]
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2024-01-31 STM32: 11-adc-scope: Add project
    Good for analyzing why one axis of the joystick for the 09-gamebox project
    sometimes moves in the wrong direction.
    [main.c, main.h]
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2024-02-20 AVR: 05-spi-with-charger: Fix total charged value were lost across reboots
    The value read from the eeprom were used by a factor 1000 too less in
    the state machine. As this value is used for statistics only, this
    had no effect of the charging behaviour.
    Also the value was truncated down to 32bit (instead of 64bit)
    when reading it for storing into the eeprom, making overflows a lot sooner
    than expected.
    A testcase is also added to detect such errors in the future.
    [main.c]
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2024-02-25 Apps: Unify main.h and stm32l4xx_hal_conf.h
    These files of the apps 04, 05, 07...11 are equal enough
    to be merged. The header of the other apps will need some
    rework to be merged.
    With the new folder structure, porting the apps to other
    MCUs now should be possible without much changes.
    [main.h]
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2024-05-05 AVR: Common: Add error code 5 to charger - too low current ARM: 05-coprocessor-control: Show error code 5
    This makes sure too high and too low charging current can be distinguished.
    [chargerStatemachine.c, control.c, main.c]
2024-05-05 AVR: Common: AVR: Common: Add debug command to read out the voltage when error 5 is reached ARM: 05-coprocessor-control: Add debug command to read out the voltage of error 5 from the coprocessor
    When the charging ends because the USB connection is removed,
    the coprocessor sometimes ends up in error 5. This command should help
    finding the reason for this behaviour.
    [configuration.h]
2024-05-05 AVR: 05-coprocessor-control: Keep ARM on for a short moment when power goes off
    When power goes off, keep the ARM on for 500ms, in the case the power will
    be restored shortly.
    This was discovered when a host PC is shut down, switching to USB standby power.
    [main.c]
2024-05-05 Coproc: 05-spi-with-charger: Fix order of input voltage and current measurement
    When the charging current is measured zero, this is only not an error if
    the input voltage is low. So this should fix the error 5 when charging is
    in progress and the USB connector is removed (needs to measure the current first,
    so removing the connector between the two measurements work).
    [main.c]
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2025-04-11 Boxlib: Put pulse audio output into a separate thread, allow configuring the simulated CPU speed
    Configuring the simulated CPU speed allows calculation of the correct sample rate depending on
    the given timer prescaler.
    Using a separate thread for audio output with a FIFO is more close to the real hardware
    where the FIFO is consumed by an ISR. Also this allows playing audio without glitches if
    creating new data takes some time.
    Apps: 14-wav-player: Adapted to provide a define for the CPU speed
    [main.h]
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2025-04-23 Apps: 15-mp3-player: Play a mp3 file over 8 bit PWM output
    Playback works. Decoding of a 128KBit/s file needs about 50% of the
    CPU cycles when running with 80MHz from RAM.
    The output buffer underruns when browsing through the files during
    playback. The output buffer size needs to be doubled to address this issue.
    Otherwise it works. But the 160KiB of the STM32L452 are completely filled
    up. This will need a rework of the boxlib, there memory could be saved.
    The framebuffer is lowered in resolution to save memory.
    Support for the smaller ST7735 based LCDs has been removed to save memory.
    Tested with (15:12.2.rel1-1) 12.2.1 20221205 from Debian 12.
    Maybe with newer compilers, compiling will f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
    [main.c, main.h]
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2026-01-13 Common: Fix linker warnings introduced with gcc-arm-none-eabi upgrade
    After upgrading the toolchain delivered by Debian 13 from the one delivered by Debian 12,
    new linker warnings emerged. We do not call these functions. But the linker gives
    warnings they are empty. Well now they are still empty, but without a compiler warning.
    [main.c]
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

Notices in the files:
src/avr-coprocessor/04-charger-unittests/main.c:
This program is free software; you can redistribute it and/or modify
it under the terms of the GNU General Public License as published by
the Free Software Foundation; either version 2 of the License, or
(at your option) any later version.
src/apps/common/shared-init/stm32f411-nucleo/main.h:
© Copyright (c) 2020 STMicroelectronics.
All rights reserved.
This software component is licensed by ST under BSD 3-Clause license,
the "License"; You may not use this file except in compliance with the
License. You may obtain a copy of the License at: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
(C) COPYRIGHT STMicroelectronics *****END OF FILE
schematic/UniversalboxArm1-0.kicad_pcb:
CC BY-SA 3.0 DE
